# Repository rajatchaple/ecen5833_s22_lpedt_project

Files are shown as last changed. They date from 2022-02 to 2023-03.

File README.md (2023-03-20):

<h1 style="text-align: center;">CUBIT</h1>

## Background
Measuring tapes have been in use for centuries and are still the primary tool for taking measurements. However, they have several limitations, including the tedious process of taking and maintaining measurements and the fact that the measurements are single-use. Therefore, our team has designed a smart measuring instrument to digitize the data, which can be easily stored and accessed from anywhere.

## Summary
Our smart measuring instrument takes precise linear and angular measurements and transmits the data over to a mobile application using Bluetooth. The device have an encoder-wheel assembly that helps take measurements over a straight or curved surface accurately. A high precision rotary encoder provides high-resolution results, while an inertial measurement unit (IMU) sensor takes different angular and device orientation data. The device is powered by a small battery and contains an energy harvesting system using solar panels to recharge the battery. The device operates in low power mode by implementing load power management and utilizing minimum current for required peripherals.

<p align="center">
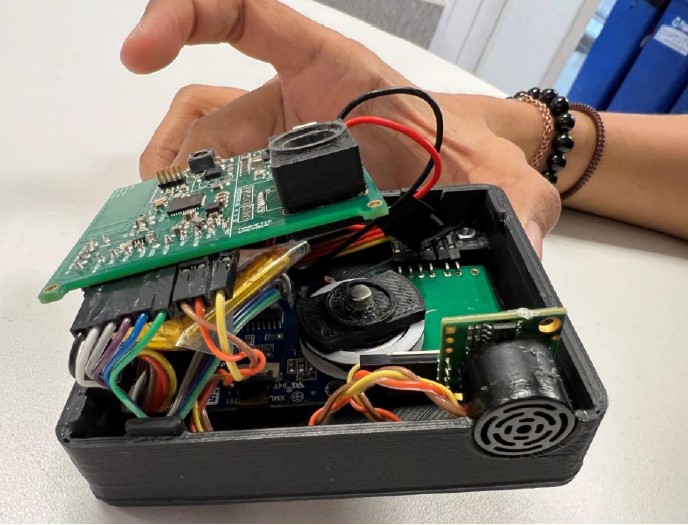
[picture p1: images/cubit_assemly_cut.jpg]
Cubit Assembly
  

## Getting Started

### Prerequisites:
* Altium Designer (for PCB design)
* Embedded C
* Bluetooth Low Energy (BLE) protocol basics
* Event-driven programming
* System design and implementation basics

### Installing:
* Install Altium Designer from [here](https://www.altium.com/downloads/altium-designer) (free for students). The project was designed using Altium Designer 22.10.1
* Install Simplicity Studio using this [link](https://www.silabs.com/developers/simplicity-studio). Set up the development environment for the EFR32BG13P732f512 microcontroller. This project works on sdk 3.2.3. It is easier to set up the environment with the [evaluation kit](https://www.silabs.com/documents/public/user-guides/ug279-brd4104a-user-guide.pdf). 

Following pages describe the approach used in development of this project over 15 weeks. This is a good example of how to design an embedded product from scratch.

## Hardware:

- [Selection of Components](https://github.com/rajatchaple/ecen5833_s22_lpedt_project/wiki/2.-Selection-of-Components)
- [Power management unit selection](https://github.com/rajatchaple/ecen5833_s22_lpedt_project/wiki/3.-Power-Management)
- [PMIC Simulation and Bulk capacitance](https://github.com/rajatchaple/ecen5833_s22_lpedt_project/wiki/4.-Bulk-Capacitance-Requirement)
- [Altium Schematic](https://github.com/rajatchaple/ecen5833_s22_lpedt_project/wiki/5.-Altium-Schematic)
- [Altium Layout Design](https://github.com/rajatchaple/ecen5833_s22_lpedt_project/wiki/6.-Altium-Layout-Design)
- [Fabrication and Assembly](https://github.com/rajatchaple/ecen5833_s22_lpedt_project/wiki/7.-Fabrication-and-Assembly)

## Software:
- LCD bring up
- IMU bring up
- Ultrasonic sensor bring up
- Encoder bring up
- Event driven programming
- BLE configuration
- Managing energy modes

## Application
Our product can be used to fulfill a majority of measurement requirements, including taking size data of a straight or uneven surface and taking angle measurements. It can be used in small industries, construction sites, fashion companies, and regular households. This product will eliminate the need to manually store measured data, and it will be low cost, low power-consuming with an energy harvesting mechanism. Additionally, it will use long-lasting rechargeable batteries, unlike single-usage dry cells.

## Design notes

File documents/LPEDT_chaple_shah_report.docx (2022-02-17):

ECEN 5833: Low Power Embedded Design Techniques

CUBIT

Smart Measuring Instrument

Team Name: Cubit

Team Members: Rajat Chaple

Saloni Shah

Table of Figures:

# Project Proposal

ECEN 5833: Low Power Embedded Design Techniques

CUBIT

Smart Measuring Instrument

Team Name: Cubit

Team Members: Rajat Chaple

Saloni Shah

## 1.1 Background

A measuring tape is used in a myriad of commercial businesses like construction, tailoring, warehouses as well as in day-to-day life. The first standard measuring tape was invented in 1850s and till now we have been using the same product. Although, since 18th century the world has advanced in every possible way, we still use the same measurement technique. The conventional measuring tape has ample of drawbacks like taking and maintaining measurements is very tedious, also all the measurements taken are majorly single use. It is high time that we modernize our method of taking measurements and digitize the data which can be easily stored and accessed from anywhere.

## 1.2 Project Summary

For the course project, our team is designing a smart measuring instrument which will have the capability to take precise linear and angular measurements and transmit the data over to a mobile application using Bluetooth. Primarily, this device will have an encoder-wheel assembly which can be used to take measurements over a straight or curved surface very accurately. A high precision rotary encoder will be helpful in giving high resolution results. Moreover, we will also install an inertial measurement unit (IMU) sensor to take different angular and device orientation data. Both measurements can then be transmitted to a mobile app connected to the product using Bluetooth. This data will also be displayed on an LCD. This device will run on a small battery, and it will also contain an energy harvesting system using solar panel to recharge the battery. All these components will be interfaced with a single Blue Gecko board. The device will operate in low power mode by implementing load power management and utilizing minimum current for required peripherals.

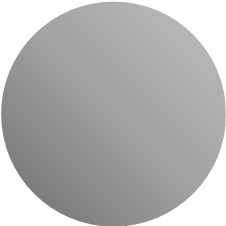
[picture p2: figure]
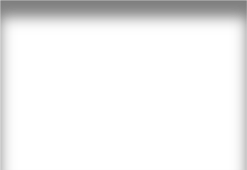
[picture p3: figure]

cm

108

0

°

Measuring Tape

Wheel fixed on

rotary encoder

LCD

Figure 1: Product Concept

## 1.3 Product Application

- This product can be used to fulfill majority of measurement requirements like taking size data of a straight or uneven surface and taking angle measurements.
- This product can be used in small industries, construction sites, fashion companies and regular households.
- This product will eliminate the need to manually store measured data.
- This product will be low cost, low power consuming with energy harvesting mechanism.
- This product will use long lasting rechargeable batteries unlike single usage dry cells.

## 1.4 Block Diagram

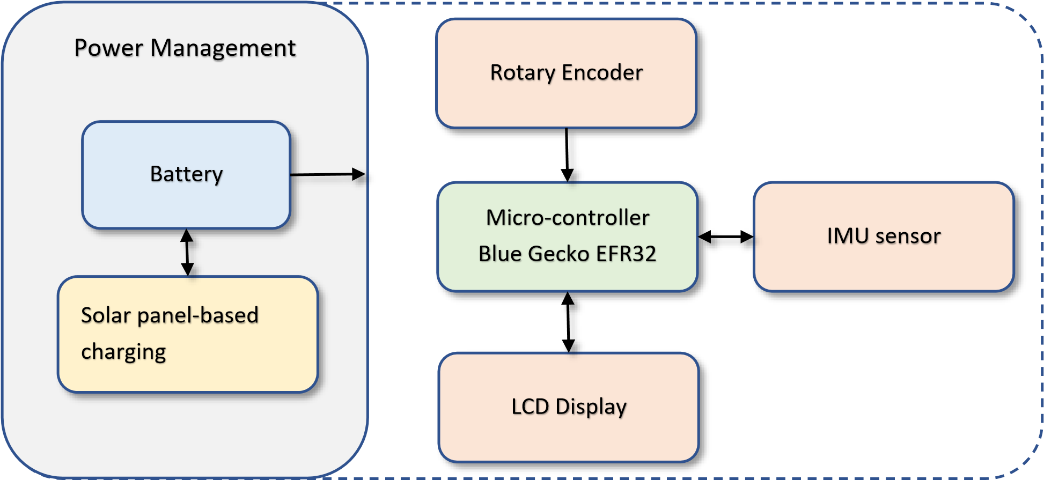
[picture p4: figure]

Figure 2: Block Diagram

## 1.5 Product Components

Table 1: Components List

Component | | Part No. | Load Power Management
Microcontroller | Silicon Labs Blue Gecko
Radio | EFR32BG13 | | ✓
Battery | Lithium Ion/Lithium Polymer | LP802036JU+PCM+2 WIRES (https://www.digikey.com/en/products/detail/jauch-quartz/LP802036JU-PCM-2-WIRES-50MM/9560981) 50MM Jauch Quartz | Batte (https://www.digikey.com/en/products/detail/jauch-quartz/LP802036JU-PCM-2-WIRES-50MM/9560981) Products | DigiKey (https://www.digikey.com/en/products/detail/jauch-quartz/LP802036JU-PCM-2-WIRES-50MM/9560981) (https://www.digikey.com/en/products/detail/jauch-quartz/LP802036JU-PCM-2-WIRES-50MM/9560981) | (https://www.digikey.com/en/products/detail/jauch-quartz/LP802036JU-PCM-2-WIRES-50MM/9560981)
PMIC | BQ25570 | BQ25570RGRT Texas (https://www.digikey.com/en/products/detail/texas-instruments/BQ25570RGRT/4430477) (https://www.digikey.com/en/products/detail/texas-instruments/BQ25570RGRT/4430477) Instruments | Integrated (https://www.digikey.com/en/products/detail/texas-instruments/BQ25570RGRT/4430477) (https://www.digikey.com/en/products/detail/texas-instruments/BQ25570RGRT/4430477) Circuits (ICs) | DigiKey (https://www.digikey.com/en/products/detail/texas-instruments/BQ25570RGRT/4430477) (https://www.digikey.com/en/products/detail/texas-instruments/BQ25570RGRT/4430477)
Buck Converter | TPS62842 Or PMIC internal buck converter | TPS62842DGRR Texas (https://www.digikey.com/en/products/detail/texas-instruments/TPS62842DGRR/12352343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) (https://www.digikey.com/en/products/detail/texas-instruments/TPS62842DGRR/12352343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) Instruments | Integrated (https://www.digikey.com/en/products/detail/texas-instruments/TPS62842DGRR/12352343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) (https://www.digikey.com/en/products/detail/texas-instruments/TPS62842DGRR/12352343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) Circuits (ICs) | DigiKey (https://www.digikey.com/en/products/detail/texas-ins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
Sensor | IMU sensor | BNO005 (To be acquired from Professor) | ✓
| Rotary Encoder | Magnetic Rotary (https://www.digikey.com/en/products/detail/ams/AS5147P-TS-EK-AB/5452349) (https://www.digikey.com/en/products/detail/ams/AS5147P-TS-EK-AB/5452349) Encoder (https://www.digikey.com/en/products/detail/ams/AS5147P-TS-EK-AB/5452349) (https://www.digikey.com/en/products/detail/ams/AS5147P-TS-EK-AB/5452349) Magnetic Wheel (https://www.digikey.com/en/products/detail/ams/RMH05-DK-XX-1-0/3712276) (https://www.digikey.com/en/products/detail/ams/RMH05-DK-XX-1-0/3712276) Assembly (https://www.digikey.com/en/products/detail/ams/RMH05-DK-XX-1-0/3712276) (https://www.digikey.com/en/product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 | ✓
| Ultrasonic Sensor | Adafruit Ultrasonic (https://www.digikey.com/en/products/detail/982/982-ND/5356850?itemSeq=389285645) (https://www.digikey.com/en/products/detail/982/982-ND/5356850?itemSeq=389285645)Sensor (https://www.digikey.com/en/products/detail/982/982-ND/5356850?itemSeq=389285645) (https://www.digikey.com/en/products/detail/982/982-ND/5356850?itemSeq=389285645) | ✓
HMI | LCD Display | Adafruit SHARP (https://www.adafruit.com/product/3502) (https://www.adafruit.com/product/3502) Memory Display (https://www.adafruit.com/product/3502) (https://www.adafruit.com/product/3502) Breakout - 1.3" (https://www.adafruit.com/product/3502) (https://www.adafruit.com/product/3502) (Acquired from Professor) | ✓
| Push Buttons | Available
Energy Harvesting System | Solar cells | Monocrystalline solar cells (https://www.digikey.com/en/products/detail/anysolar-ltd/KXOB25-12X1F-TB/9990434)

## 1.6 Proposed Product Demo

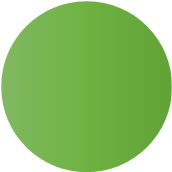
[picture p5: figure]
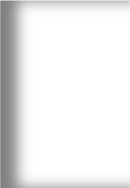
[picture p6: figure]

0

c

m

0

°

Measuring Tape

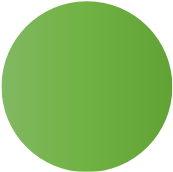
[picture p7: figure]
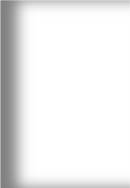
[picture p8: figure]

cm

36

0

°

Measuring Tape

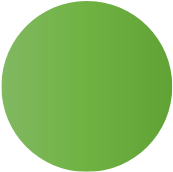
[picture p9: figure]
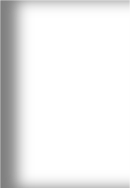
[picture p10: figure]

108

cm

0

°

Measuring Tape

Figure 3: Proposed Product Demo 1

As shown in the above image, this measuring tape can be used to measure any surface. The wheel encoder assembly installed on the product can be slid over a flat or uneven surface to get size value accurately. This measuring tape will have a high resolution in centimeter because of the use of a precision Rotary encoder with large number of pulse detection in a single rotation.

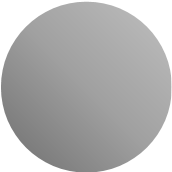
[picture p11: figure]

108

cm

0

°

Measuring Tape

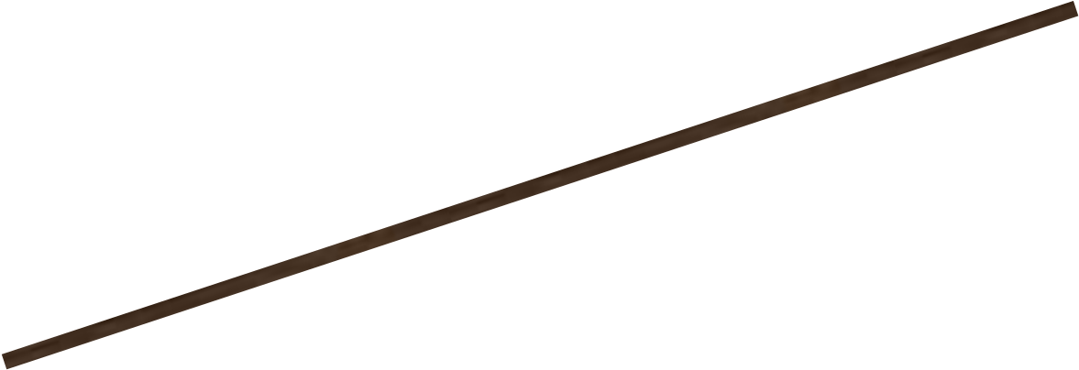
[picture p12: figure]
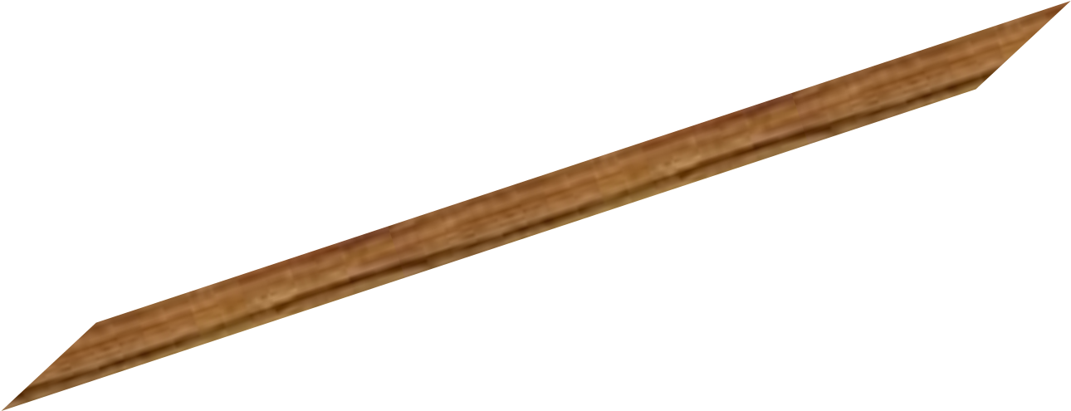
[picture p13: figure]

Figure 4: Proposed Product Demo 2

The above image shows how an angle measurement can be carried out using the product. This angle can be measured in any orientation of the device. The angle measurement will also be highly accurate due to the IMU sensor.

## 1.7 Product Features

- Free android app to store and manage measurement data
- Bluetooth connectivity of mobile phone with the device
- Rotary encoder-wheel assembly for linear measurement
- IMU sensor for accurate angle measurement
- LCD Display for better user experience
- Energy harvesting mechanism using solar panels
- Load power management by turning on only required peripherals
- Single rechargeable LiPo battery which can power the complete device

## 1.8 Product Specifications

- Dimensions: 100mm x 70mm
- Weight: 100g
- Wireless range: 100 m
- Size accuracy: ± 1 cm
- Angle accuracy: ± 1°
- Product Warranty: 2 years
- Operating Temperature: 0°C - 65°C
- Internal sensors and peripheral operating temperature:

Table 2: Temperature specifications for sensors

Sensor | Operating Temperature Constraints
Blue Gecko | -40 to 85 °C
IMU | -40 to 85 °C
Rotary encoder | -40 to 150 °C
LCD Display | -40 to 70 °C

# 1 Project Update 2

ECEN 5833: Low Power Embedded Design Techniques

CUBIT

Smart Measuring Instrument

Team Name: Cubit

Team Members: Rajat Chaple

Saloni Shah

Date: 01/29/2022

## 1.1 Activities accomplished in past week

- Studied mouse scroll-wheel encoder assemblies to decide the decide the mechanical assembly for final product. Disassembled 4 different optical mouses to explore different assemblies.

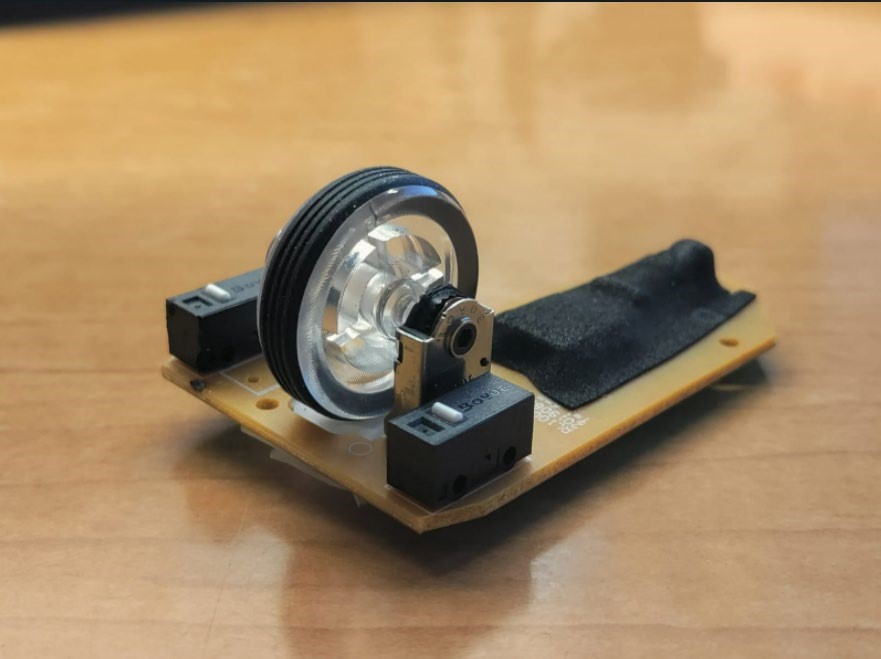
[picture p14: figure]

Figure 5: Scroll wheel encoder assembly

- Measured PPR(Pulse per rotation) of rotary encoder and circumference of wheel to estimate linear measurement resolution. o Finalized ultra-low power Graphic LCD display. o Estimated total power and energy consumption of the product.
- Worked on project planning and estimated timeline.

## 1.2 Activities for the coming week

- Finalize battery and solar panel based on energy consumption requirements. o Finalize Power management IC.
- Work on power supply circuit for the product.

## 1.3 Energy model for the product:

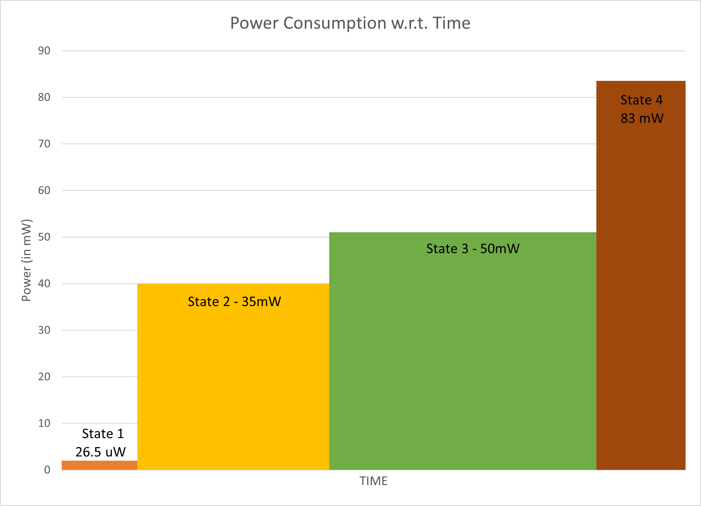
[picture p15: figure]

Figure 6: Energy model

## 1.4 Sensor selection:

### 1.4.1 IMU Sensor: BNO005

    - This sensor works on I2C as well as UART.
    - We will be interfacing the sensor using I2C as data transfer over UART communication takes longer and even though it consumes less energy, overall efficiency of UART decreases. Moreover, for transfer of larger data bytes I2C consumes the same amount of energy. (These assumptions were made using this reference (http://cc.oulu.fi/%7Ekmikhayl/site-assets/pdfs/2012_NTMS.pdf). (http://cc.oulu.fi/%7Ekmikhayl/site-assets/pdfs/2012_NTMS.pdf))
    - This sensor will require external load switch as after start-up it only enters low power mode and suspend mode. (Even in suspend mode it consumes 40uA of current).

### 1.4.2 Rotary encoder

    - This mechanical encoder has just 2 digital pins which can be wired directly as input to the controller. The encoder generated pulses gives the angular position of the axis and can then be converted to digital output.
    - The encoder will also require external load switch as it does not have internal circuitry to turn power off.

Online Project Management using Monday.com (https://view.monday.com/2210043877-dee7e4668b7b619c0c4a18486899a087?r=use1) (https://view.monday.com/2210043877-dee7e4668b7b619c0c4a18486899a087?r=use1)

## 1.5 Program Flowchart:

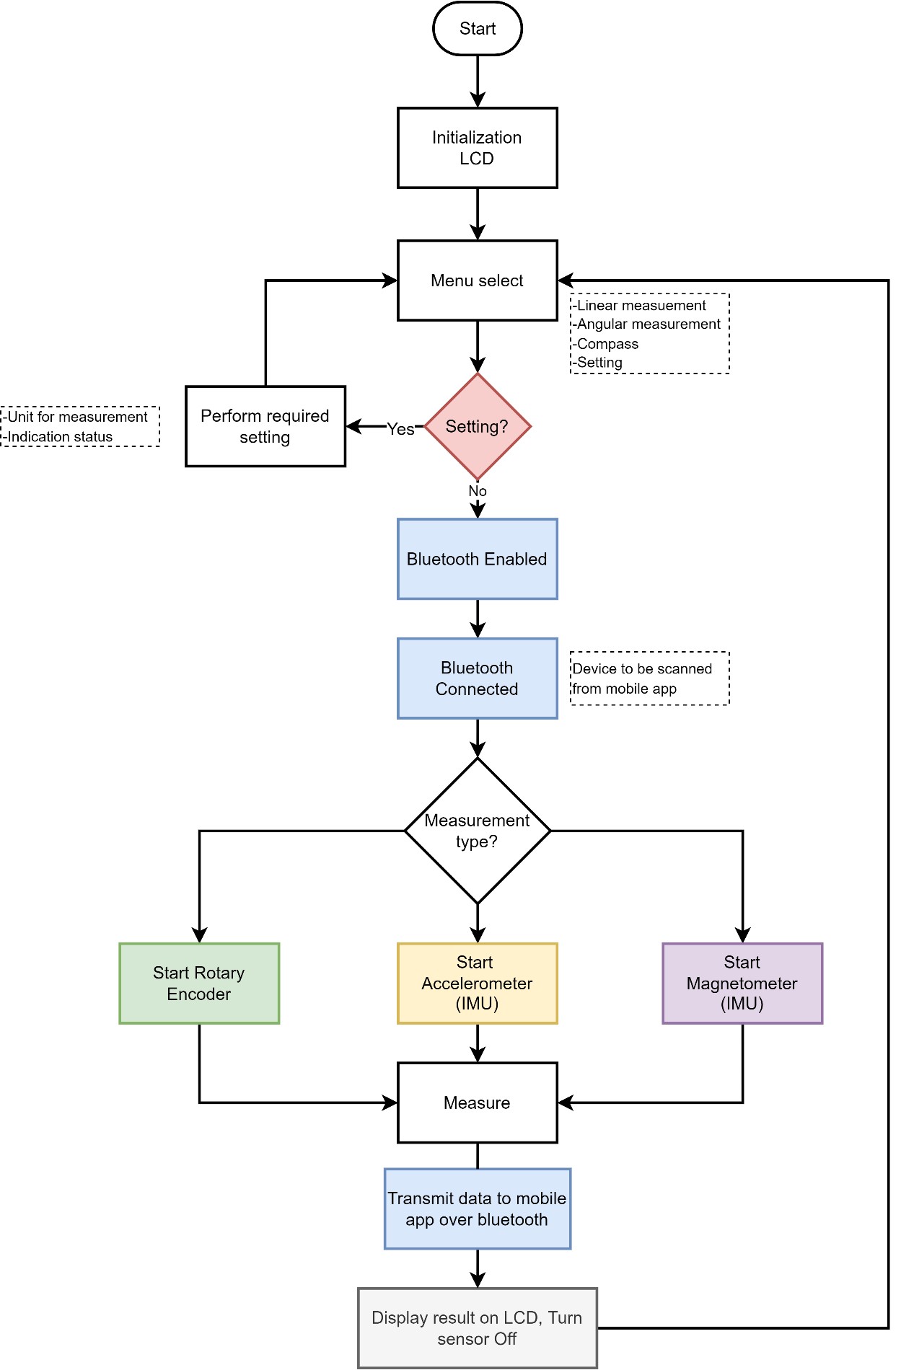
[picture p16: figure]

Figure 7: Flowchart

# 2 Project Update 3

ECEN 5833: Low Power Embedded Design Techniques

CUBIT

Smart Measuring Instrument

Team Name: Cubit

Team Members: Rajat Chaple

Saloni Shah

Date: 02/05/2022

## 2.1 Activities accomplished in past week:

- Finalized energy storage element (battery) based on energy consumption requirements.
- Finalized Power management IC and buck-converter IC.
- Practically implemented measurement system using mechanical rotary encoder, string-pulley assembly and interfaced it with Arduino. Found out that the rotary encoders have a limitation on how fast it can detect rotations i.e. it can only detect signals correctly at less than 160 rpm.

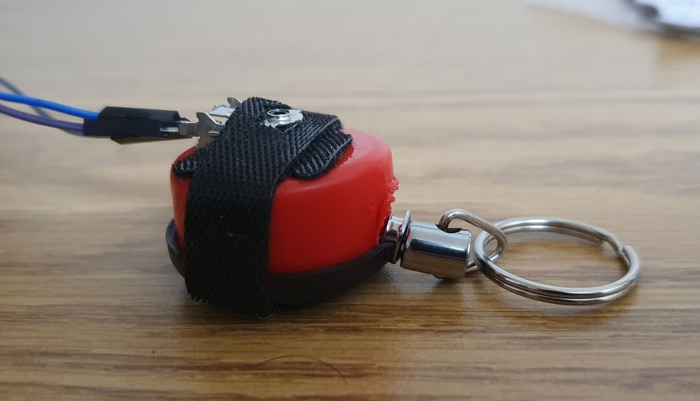
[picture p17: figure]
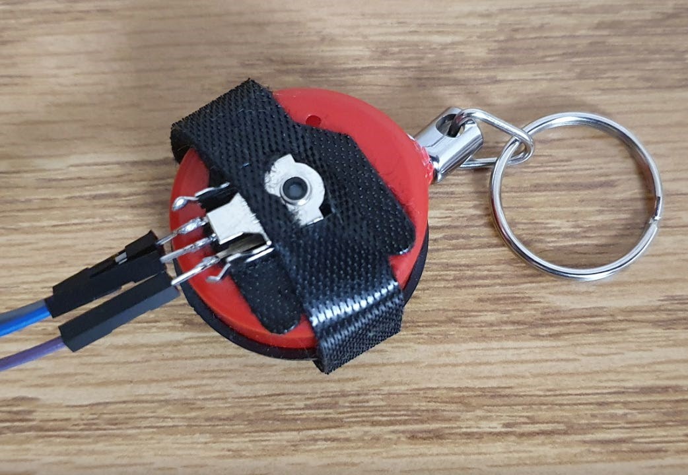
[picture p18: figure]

Figure 8: Assembled rotary encoder with a string-pulley

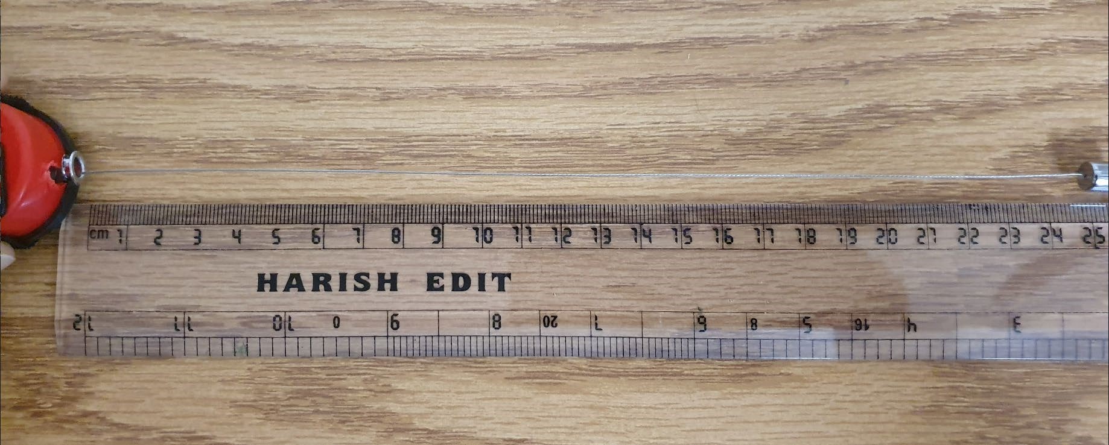
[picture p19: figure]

Figure 9: Measuring the length of a ruler using the assembly

Arduino serial monitor output with number of pulse counts and calculated length

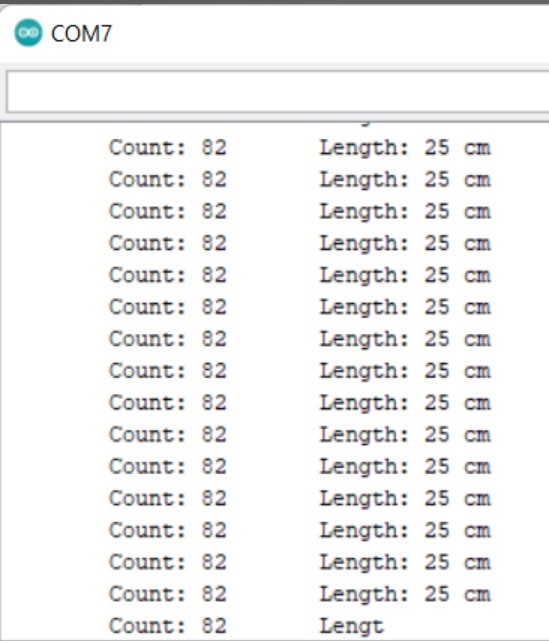
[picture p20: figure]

Figure 10: Optical Rotary Encoder output

- Changed the required rotary encoder from mechanical to magnetic due to speed constraints and higher chances of signal misses in the mechanical encoder.
- Finalized required magnetic rotary encoder and ultrasonic sensor for measurement applications.

## 2.2 Activities for the coming week

- Finalized energy harvesting element (solar panel) based on energy consumption requirements.
- Design product power supply circuit.
- Interface LCD display with Blue Gecko Evaluation Module.
- Finalize other required components for the product schematic design.

Power Storage Element Selection

o Expected runtime using supercapacitor = 1.36 hours

o Expected runtime using battery = 3 days (8 hours per day)¹

### 2.2.1 Super Cap vs Battery

Required peak current: 25 mA

Average current consumption: 13.68 mA

Average Charge requirement for continuous 8 hours operation: 110mAh

Average Energy Required for 8 hours of operation: 328.4 uWh

Ambient Temperature Conditions: Room Temperature (about 25° C)

Table 3: Super cap - Battery comparison

Super Cap | Battery
Steep discharge curve | Higher operating time
Large leakage current (30 uA) | Very less leakage current (2%/year)
Cannot handle required peak current | Can handle upto 1A peak current
Lower energy density | Higher energy density
Can operate in very low temperature | Dispenses less energy in low temperatures
Lower ESR power loss | Higher ESR power loss

Table 4: Supercap and battery specifications

Design Requirements | Super Cap (Tecate 100F) | Battery (Jauch 480mAh)
Useable Energy | 234.5J² - 18.6mAh | 480 mAh
Peak Discharge Current | | 1A
Recharge time | | 2 hours @ 0.5C
2 years of use, 300 charges | 500,000 cycles | 300 cycles ~ 80% capacity usage
Leakage current or rate | 3 uA | Less than 2-3%
ESR | 210 mΩ
Mechanical Dimensions | 12.5 x 25 mm | 38 x 20.5 mm

1 Refer attached spreadsheet for calculations
2 Refer attached spreadsheet

## 2.3 Power Management Unit Selection

### 2.3.1 Determining the required voltage range for the product

o To decide the operating voltage range for the product, we looked at the input voltage range of the peripherals utilized in the system. The below table shows the minimum and maximum input voltage range of the sensors and MCU.

Table 5: Voltage range for components[^1]

Sensor | Vin(min) | Vin(max) | Current Consumption
Blue Gecko | 1.8V | 3.8V | 4uA
IMU | 2.4V | 3.6V | 12.3mA
Rotary encoder | 3V | 3.6V | 15mA
LCD Display | 3V | 5V | 4uA

      - Based on the above calculations, we decided to operate all the peripherals at 3.0V as to utilize maximum possible battery capacity and increase the operating time of the system.
      - The approximate range of the supply voltage will be from 3.0-3.6V.

### 2.3.2 Determining the power management topology

- Considering that the power source battery gives maximum 3.7V and our required voltage supply for the peripherals is about 3.0V, which is always lower than supply voltage we decided to implement a buck converter to meet our power requirements.
    - The primary reason for choosing a buck converter as opposed to a buck-boost is that most Lithium-Poly batteries have a plateau from 3.5-3.6V

and very little charge below this plateau, limiting the usefulness of the buck-boost converter and its wide input voltage range[^2].

      - Moreover, the buck-boost converter also has one additional MOSFET as compared to the buck converter which increases power loss and decreases efficiency of the converter.
      - Keeping this in mind, we searched for a buck converter IC, with high efficiency, low quiescent current, low cost, and smaller footprint.
      - All these requirements were successfully met by the buck converter TPS62840[^3].

### 2.3.3 Determining Regulated or Unregulated Power Source

    - While deciding whether to use regulated or unregulated power source, we carried out following calculations to understand efficiency of both topologies.

Assumed product usage of 60 minutes or 3600 seconds

Assumed number of measurements in 1 hour, average of 20 measurements

Assumed period for one measurement, average of 13 seconds

On duty cycle = (20 measurements * 13 seconds) / 3600 = 7.2% Off duty cycle = 92.8%

TPS62840 Buck converter Efficiency Curve

    - Off duty cycle = 0.015-0.020 mA

Estimated 87.5% efficiency

    - On duty cycle = 15-20 mA range

Estimated 94% efficiency

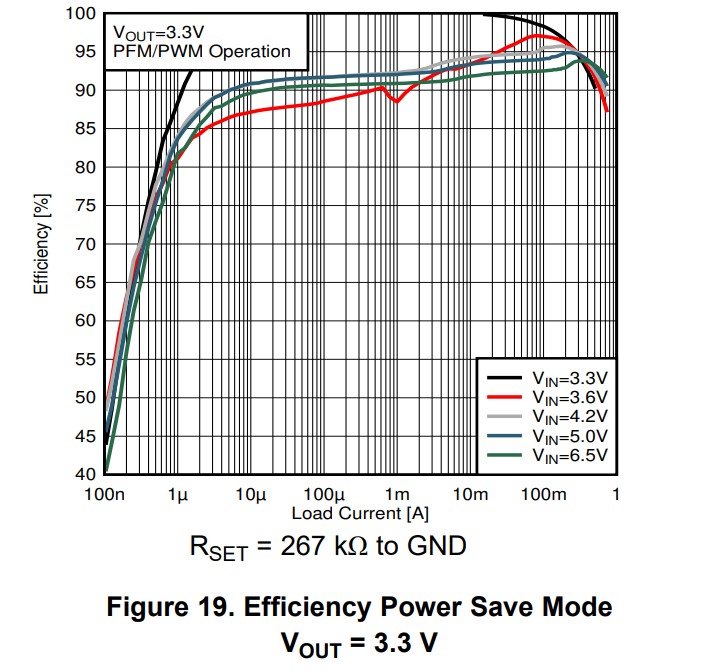
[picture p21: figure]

For regulated power case (using TPS62840 buck converter):

    - On duty cycle
    - TPS62840 efficiency ~3.6V input and 15,500uA is 94% + 0.06uA Iccq
    - Weighted avg power OOB = (On duty cycle * (15500 + 0.06) * 3.0V) / 94%
    - Weighted average power out of battery = 3561 uW o Off duty cycle
    - TPS62840 efficiency ~3.6V input and 20uA is 87.5% + 0.06uA Iccq
    - Weighted avg power OOB = (Off duty cycle * (20 + 0.06) * 3.0V) / 87.5%
    - Weighted average power out of battery = 63.8 uW o Total Average Power out
    - Weighted on duty cycle average power + Weighted off duty cycle average power = 3561uW + 63.8uW = 3624.825 uW

For unregulated power case (using Blue Gecko internal LDO):

- On duty cycle
    - Gecko efficiency ~3.6V input and 15,500uA is 83.33%
    - Weighted average power OOB = (On duty cycle * 15500 * 3.0V) / 83.33%
    - Weighted average power out of battery = 4017.7 uW o Off duty cycle
    - Gecko efficiency ~3.6V input and 20uA is 83.33%
    - Weighted average power OOB = (Off duty cycle * 20 * 3.0V) / 83.33%
    - Weighted average power out of battery = 66.81 uW o Total Average Power out
    - Weighted on duty cycle average power + Weighted off duty cycle average power = 4017.7uW + 66.81uW = 4084.5 uW

Increase in battery life using regulated power = 1 -

= 11.25%

Based on above calculations, we decided to use a regulated power source since it provides longer battery life. Moreover, we have a higher on duty cycle, higher power on to power off ratio, higher efficiency at light load and low quiescent current which justifies the use of regulated power source.

4.4. Determining the Power Management IC o The primary criteria for selecting a PMIC were low minimum input voltage limit to support very low voltage from energy harvesting element (solar cell) and efficient boost converter. A simple and efficient circuitry for energy harvester is required which were available in PMIC BQ25570.

- The input voltage supported in this IC is 0.1-5.1V. Also, many typical solar cells have an output voltage of 0.1V.
- Another important criterion is to have a wide range of input voltage from battery to support lower battery power which is 2-5.5V in case of BQ25570.
- This IC also has higher charging current capacity (maximum 285mA) for fast charging from external charger or a USB charging port.
- BQ25570 also has internal Programmable Maximum Power Point Tracking (MPPT) circuitry for optimal energy extraction from energy harvester like solar panel.
- Moreover, BQ25570 has internal boost as well as buck converter to boost low input voltage from the energy harvester and simultaneously regulate the output voltage[^4].

# 4 Project Update 4

ECEN 5833: Low Power Embedded Design Techniques

CUBIT

Smart Measuring Instrument

Team Name: Cubit

Team Members: Rajat Chaple

Saloni Shah

Date: 02/12/2022

## 4.1 Activities accomplished in past week:

- Generated Altium components library for following parts

Table 6: Components' library list

Sr. No | Part Description | Part Number | Footprint Name | Online SnapEDA/ Octopart Link
1 | Blue Gecko | EFR32BG13P732F512GM48-D | 48-QFN_7x7 | N/A
2 | PMIC | BQ25570RGRT | 21_QFN_35X35 | N/A
3 | IMU Sensor | BNO055 | LGA28R50P4X10_380X520X100 | BNO055 SnapEDA (https://www.snapeda.com/parts/BNO055/Bosch%20Sensortec/view-part/)
4 | Magnetic Encoder | AS5147P-HTSM | 14-TSOP_5x4_4 | N/A
5 | Resistor | RMCF0603FT1K00 | 2_Chip_0603_RMCF | N/A
6 | Capacitor | CL10A475KP8NNNC | CAP_0603_1MM | N/A
7 | Inductor | VLS3015CX-220M-1 | 2_IND_3x3 | N/A
8 | LED (red) | 150060RS75000 | LED_0603_RED_WL-SMCW | N/A
9 | LCD header | 3502 | LCD_SHARP_MEMORY_9_PIN | N/A

### 4.1.1 Change in the Power management strategy

  - With earlier update, plan was to use PMIC bq25570 and TPS62842 buck converter. Criterion for selection of external buck converter instead of one already integrated into bq25570 was Efficiency. However, considering ON duty cycle of the product operation, efficiency would no longer be a preliminary factor under consideration.
  - Also, major concern where we cannot utilize most energy from the battery was resolved using following.
    - Entire circuit would work at 3.15v
    - Buck converters have dropout voltage. This limits battery’s minimum usable voltage. As per datasheet, dropout voltage is maximum output current times the buck high side resistance.

Calculations:

Maximum output current: 35 mA

Maximum buck high side resistance: 200Ω

Dropout voltage: 35 x 200 = 0.7v

    - Usable battery would be in the range of 3.7v down to 3.22v.

### 4.1.2 Tested battery power consumption from a sample project

  - As a case study one of the sample projects was arranged. Though this project’s objective is entirely different than that of CUBIT, similarities in functional blocks were identified. This project also contains solar energy harvesting, PMIC and a load.

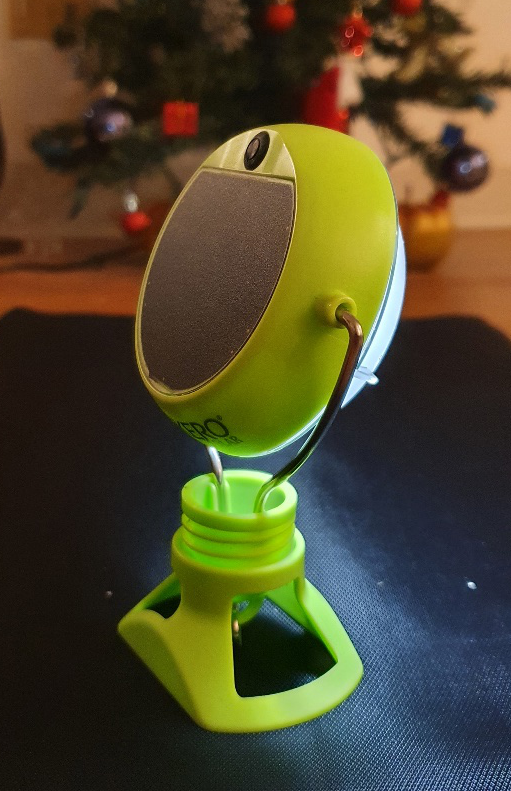
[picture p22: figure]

Energy Harvesting unit

Load
(Power LED)

Battery

(300 mAh)

Figure 11: Sample Product for case study

Calculations:

Continuous current consumption by Power LED = 55 mA

Theoretical battery backup=(Battery capacity(mAh))/(Continuous current consumption)

=500/55=9.09 Hrs

Objective: Solar power lamp

Battery capacity = 500mAh

No of Solar cells = 7 (part number unknown)

LEDs: 1 power LED of typical current consumption of 50mA

Solar Panel

Microcontroller

LED Driver

LED

Battery

Sample Project Block Diagram

Practically measured battery backup: 9 hours

If current consumption was 18mA, we would get battery backup of ~27 Hrs

Outcome of the experiment:

Our calculation for CUBIT falls between this range where battery backup for 480 mh battery with 18mA avg current consumption is around 24 Hrs. This verifies calculations against practical measurements.

  - Finalized solar cell unit

Calculations:

As per calculations in spreadsheet bq25570SolarAppDesign.xlsx,

Minimum solar panel area required is 8mW/cm²

As per datasheet: solar cell (https://waf-e.dubudisk.com/anysolar.dubuplus.com/techsupport@anysolar.biz/O18Adzn/DubuDisk/www/Gen2/KXOB25-12X1F%20DATA%20SHEET%20202007.pdf) (2994-KXOB25-12X1F-TB-ND), maximum peak power is 24.5mW per 1.54 cm²

This implies power/cm² =24.5mW/1.54cm^2

=15.90mW/cm^2

Selected component satisfies this requirement of minimum 8mW/cm²

### 4.1.3 Version tracking using GitHub

Updated previous updates, libraries and calculation documents to github

rajatchaple/ecen5833_s22_lpedt_project (github.com) (https://github.com/rajatchaple/ecen5833_s22_lpedt_project)

### 4.1.4 Timing information

Following are the critical timing parameters per module.

Table 7: Timing Information

Device | Parameter | Description | Min | Max
AS5147 (SPI) | tL | Time between CSn falling edge and CLK rising edge | 350 ns
| tH | Time between last falling edge of CLK and rising edge of CSn | 50 ns
| tMOSI | Data input valid to falling clock edge
BNO055 | fSCL | Clock frequency | | 400kHz
| fSUDAT | SDA Setup Time | 0.1 us
| HDDAT | SDA Hold TIme | 0 us
SHARP Memory LCD | fSCLK | Clock Frequency | | 1.1MHz
| tsSCS | SCS Setup time | 6 us
| thSCS | SCS hold time | 2 us
| tsSI | SI setup time | 250 ns
| thSI | SI hold time | 350 ns

### 4.1.5 Calculations for PMIC IC

- Studied reference design in bq25570 user guide (https://www.ti.com/lit/ug/sluuaa7a/sluuaa7a.pdf?ts=1644694996855) in order to understand PMIC circuitry for our application.
- Also, used calculator provided by TI on BQ25570 data sheet, product information and support | TI.com (https://www.ti.com/product/BQ25570) to calculate Resistor values.

### 4.1.6 Battery specifications

Table 8: Battery specifications

Parameter | Value
Battery nominal Voltage | 3.7V
Typical capacity | 500mAh
Minimum capacity | 480mAh
Charge voltage | 4.2V
Standard current | 0.2C-100 mA
Max charging current | 0.5C – 250mA
Cut-off voltage | 3V
Max discharging current | 2C-1A
Power rating | 1.78Wh

Battery Tolerances

Table 9: Battery Tolerances

Parameter | Value
Overcharge voltage | 4.28 V ± 0.025 V
Overdischarge voltage | 3.00 V ± 0.05 V
Over current range | 1.0A to 4.0A
Charging operating temperature | +10°C to +45°C
Discharging operating temperature | -20°C to +25°C

### 4.1.7 High risk elements:

- Magnetic interference of two sensors
  - IMU has a magnetometer which is to be used for compass and the rotary encoder is also based on magnetic pulse. These two components can interfere with each other and show incorrect reading. As a measure to mitigate this risk, we will be placing the two components physically as far as possible from each other on the board.
- EMI interference
  - Similar to the issue mentioned, the magnetic field from these components can also generate electromagnetic interference which can disrupt the functionality of other components on the board especially inverted F-antenna for Bluetooth connection (radio frequency can be disrupted due to electromagnetic interference). The potential solutions to overcome EMI are filtering, shielding, or grounding.
- Dual charging system (USB and Solar cell)
  - As a power storage component, we are using a rechargeable LiPo battery. To recharge this battery, we are planning on using energy harvesting component - solar cells. Apart from the solar cells, we also intend to have a 5V USB charging port on the board.
  - The major drawback in this design is the unavailability of a power management IC to efficiently switch between solar cells and USB port. Even if we interface a USB port, we have to have a circuit design such that reverse current does not flow from battery to our energy harvesting device and also to automatically switch between solar energy and USB input.
  - In this circuit design, we plan to use Schottky diodes for fast switching and low voltage drop. In case we are unable to successfully implement this design, we will be eliminating use of USB charging port and use the solar power as our primary recharge source.

### 4.1.8 Project Schedule:

Table 10: Project Schedule

Task | Deadline
Altium Components Libraries | Feb 12, 2022
Altium Product Schematic | Feb 26, 2022
Altium Product Layout | March 5, 2022
Product Final Layout for Fabrication | March 12, 2022
Send PCCB board for fabrication | March 19, 2022

We are aligned with our project timelines except the task where our plan was to bring up LCD module last week. We will be achieving this task in upcoming week. Instead, this week we focused on our case study of sample project to verify our energy calculations.

## 4.2 Activities planned for the upcoming week:

- Finalizing Bulk capacitance
- Implement LCD driver
- Schematic of Power Management Unit

[^1] IMU datasheet: BNO055 Datasheet (mouser.com) (https://www.mouser.com/datasheet/2/783/BST_BNO055_DS000-1509603.pdf) (https://www.mouser.com/datasheet/2/783/BST_BNO055_DS000-1509603.pdf) Blue Gecko datasheet: (https://www.silabs.com/documents/public/data-sheets/efr32bg13-datasheet.pdf)EFR32BG13 Data Sheet: Blue Gecko Bluetooth® Low Energy SoC Family (silabs.com) (https://www.silabs.com/documents/public/data-sheets/efr32bg13-datasheet.pdf) (https://www.silabs.com/documents/public/data-sheets/efr32bg13-datasheet.pdf) Magnetic Rotary Encoder datasheet: (https://www.digikey.com/en/products/detail/ams/AS5147P-TS-EK-AB/5452349)AS5147P-TS_EK_AB ams | Development Boards, Kits, Programmers | DigiKey (https://www.digikey.com/en/products/detail/ams/AS5147P-TS-EK-AB/5452349) (https://www.digikey.com/en/products/detail/ams/AS5147P-TS-EK-AB/5452349)LCD Display datasheet: (https://cdn-shop.adafruit.com/product-files/3502/Data+sheet.pdf)Data+sheet.pdf (adafruit.com) (https://cdn-shop.adafruit.com/product-files/3502/Data+sheet.pdf) (https://cdn-shop.adafruit.com/product-files/3502/Data+sheet.pdf)
[^2] EETimes - Buck-boost vs. buck converter: it's about battery life in portables (https://www.eetimes.com/buck-boost-vs-buck-converter-its-about-battery-life-in-portables/) (https://www.eetimes.com/buck-boost-vs-buck-converter-its-about-battery-life-in-portables/)
[^3] TPS62840 datasheet: (https://www.ti.com/lit/ds/symlink/tps62840.pdf?HQS=dis-dk-null-digikeymode-dsf-pf-null-wwe&ts=1644076764086)TPS62840 1.8-V to 6.5-V, 750-mA, 60-nA IQ Step-Down Converter datasheet (Rev. D) (https://www.ti.com/lit/ds/symlink/tps62840.pdf?HQS=dis-dk-null-digikeymode-dsf-pf-null-wwe&ts=1644076764086) (https://www.ti.com/lit/ds/symlink/tps62840.pdf?HQS=dis-dk-null-digikeymode-dsf-pf-null-wwe&ts=1644076764086) (ti.com) (https://www.ti.com/lit/ds/symlink/tps62840.pdf?HQS=dis-dk-null-digikeymode-dsf-pf-null-wwe&ts=1644076764086) (https://www.ti.com/lit/ds/symlink/tps62840.pdf?HQS=dis-dk-null-digikeymode-dsf-pf-null-wwe&ts=1644076764086)
[^4] BQ25570 internal buck converter vs external TPS62840 buck converter: The TPS62840 buck converter has higher efficiency at low current consumption than the internal buck converter.

Project Update #3

Project Update #4

Project Proposal

Project Update #2

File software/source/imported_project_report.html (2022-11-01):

# Project Import Summary

Import time | Apr 11, 2022, 3:45:45 PM
Original location | C:\Users\rajat\OneDrive\Low Power\Project\github\ecen5833_s22_lpedt_project\software\source\.cproject
Original project name | source
Original project type | Simplicity Studio (.sls)
Import mode | Copy contents

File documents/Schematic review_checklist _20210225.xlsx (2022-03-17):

 |  | Schematic Entry Review worksheet (Verstion 10-05-2019) | Schematic Entry Engineer Review comments /justifications | Partner 1 Engineer Schematic Review comments | Partner 2 Engineer (If team of 3) Schematic Review comments | SA Schematic Review 1 Comments | SA Schematic Review 2 Comments
 |  | Date: | 2022-02-27 | 2022-02-27
 |  | Engineeer/ Reviewer Name: | Saloni Shah | Rajat Chaple
 |  | Project name: Cubit
 |  | Circuits: Power Management, IO connection, Sensor interfacing, radio interface, HMI interface
1. Symbol Generation
 | a. Review all custom made .schLib files.
 |  | i. Verify that the schematic symbol is appropriate for the device function. | Schematic symbol designed using reference application design from datasheet | Schematic symbols verified
 |  | ii. If symbol is multipart, verify functional divisions make sense | Multipart symbols are EFR32 and BNO055. EFR32 has 3 parts - radio and antenna interface, IO port, power decoupling and supply. BNO055 has 2 parts - application pin connections and noconnect pins | Multipart symbols verified
 |  | iii. Make sure all component pins are accounted for on symbol(s). (Count them!) | Verified | Verified
 |  | iv. Verify the schematic pin #s match the data sheet. | Verified | Verified
 |  | v. If thermal pad is required, verify that a pin is specified for the pad and connected to ground. | Thermal pad is required in EFR32, BQ25570 only. Pads connected to ground. Verified | Thermal pads verified. Pads adjusted in footprint as well to get appropriate solder mask
 |  | vi. Review that the same IC package is selected on the merchant website and on the parameter entry in schematic symbol. | Verified | Verified
 | b. Verify that all the Parts have their part numbers updated. |  | Verified | Verified
 | c. Verify that all the segments of a multipart component have the same reference designator assigned. |  | Verified | Verified
2. Component Selection
 | a. Decoupling capacitor selected should be rated for 175 to 200% of the voltage on the rail. |  | 220uF and 100uF used in PMIC bulk capacitance and decoupling capacitance is rated at 6.3V, this was the highest available value. Rest of the capacitors are rated at higher voltages | Verified
 | b. Guideline, not rule: All resistor 0603 or justify a different size |  | All resistors used are 0603 | Verified
 |  | i. space constraints demand smaller, (don’t go smaller than 0402)
 |  | ii. or use case power requires larger
 | c. Guideline, not rule: All Caps 0805 or justify a different size |  | Most capacitors used are 0805 | Verified
 |  | i. space constraints demand smaller, (don’t go smaller than 0402)
 |  | ii. or capacitance requires larger package, | 220uF capacitor is larger (1210) as smaller size is not available | Capacitance calue verified using SimSurfer taking into account DC bias
 |  | iii. or smaller part required to achieve desired response frequency. | Smaller capacitance on antenna connection require 0402 part | Verified
3. Page Layout
 | a. Block diagram on first page. |  | Done by Rajat | Completed
 | b. Functional blocks grouped logically on pages |  | Verified | Verified
 | c. Pages not overcrowded |  | Verified | Verified
 | d. Schematics designed to print on 8.5 x 11” page (OK to use 'B' size sheet and shrink to print.) |  | Verified | Verified
 | e. Title blocks on all pages? Properly filled in? |  | Verified | Verified
4. Design
 | a. For every IC
 |  | i. Check voltages on each part. Verify that signals connecting devices are at the same voltages or are open collector (open Drain) signals. | All components can be configured between 3-3.6V. We are operating them at 3.2V for maximum battery usage | VOUT of 3.2V gives satisfies minimum requirement of all circuit components
 |  | ii. Check whether each signal pin is open drain, and if yes, is there a pull-up resistor. | N/A | N/A
 |  | iii. Verify the no device on a given bus will be powered down and pull the bus signals low when other devices are trying to communicate. | Verified | Verified
 | b. Go through the PMU datasheet to understand the settings.
 |  | i. Verify that the maximum voltages on any pins are within the device’s PMU specifications. | Verified | Verified
 |  | ii. Go through each PMU pin specification in order of the data sheet | Verified | Verified
 |  | iii. Check whether each pin requires a decoupling capacitor. | Verified (followed typical application for guidance) | Verified
 |  | iv. Show math for calculating all feedback components - best to show math on schematic. | Calculated using the excel sheet resource provided by TI | Verified the excel sheet calculation with equations given in PMIC datasheet
 |  | v. Show math for calculating all compensation components - best to show math on schematic. | Calculated using the excel sheet resource provided by TI | Verified the excel sheet calculation with equations gven in PMIC datasheet
 | c. What is the planned cut-off voltage of the battery? |  | 2 V
 |  | i. Confirm that the PMU is set to disable power to the digital circuit when the battery goes below the cut-off voltage | Internally managed by the PMIC | Verified
 | d. If design is different from reference schematic from vendor, why? |  | Same design except addition of Bulk capacitance on VSTOR and schottkey diode assembly on LBOOST input to handle input from USB connector | Design change verified by detailed study of PMIC datasheet
 |  | i. Justify changes
 | e. If super capacitor is chosen as the storage device, check for the leakage current. |  | N/A | N/A
 | f. Verify if the different modules can be isolated from each other to ease the testing process. |  | Load switches are connected before each sensor and LCD module for isolation. Jumper connection is added between PMIC and microcontroller for isolation | Load switches connected between power from microcontroller correctly. Can have additional jumpers before load switches for testing during development
 | g. Add a header on the energy harvester to check for current consumption. |  | Test point added on the solar panel output | Verified
 | h. If using UART and if the microprocessor is an EFM32LG, an external oscillator will be required as the RC Oscillator isn’t accurate enough to run at 9600 baud rate. |  | N/A | N/A
 | i. Every power pin on a part or header should have a decoupling capacitor. |  | Verified | Verified
 | j. Does design have an appropriate programming connector or method? |  | Debug connector added to EFR32 | Debug connector interfacing verified from AN958
 |  | i. Does design provide enough power for programming MCU or does it have an alternate programming power connection? | No alternate programming power connection required | Verified
 | k. Can battery or cap be initially powered in reasonable time?
 | l. Does schematic have extra GND test point pins to be spread around board? (6-8?) |  | Not required. All test points have adjacent ground connection | Verified
 | m. Test point pins on busses? |  | Verified | Verified
 | n. Test point pins on interrupts? |  | Verified | Verified
 | o. Extra test pins on spare IO for scope triggers for profiling? |  | Verified | Verified
 | p. Consider adding LED indicators, especially on the power rails and add it close the subsystem under test (easy to identify if the subsystem is powered on/off). |  | Added indicator LEDs on multiple parts of the board | Verified
5. Wiring
 | a. Verify the direction and use of the LEDs. |  | Verified | Verified
 | b. Verify that the GNDs have all the same name where ever required. |  | Verified | Verified
 | c. Verify that all appropriate power lines have the same name. |  | Verified | Verified
 | d. Verify any communication lines:
 |  | i. If one part will be active while another one is powered off on the line, is there a condition where an ESD diode could be pulling the line down? | No such connection made | Verified
 | e. Verify whether any UART RTS and CTS lines need to be shorted or left open. |  | Not required. | Verified
 | f. Verify that the micro controller UART TX pin connects to the RX pin of the slave device and that the TX pin of slave device connects to the RX pin of the microcontroller. |  | Verified. Ultrasonic sensor output TX pin is connected to EFR32 RX pin | Verified
 | g. Verify that the RESET pin is connected correctly as per the functionality (Active Low/Active High). |  | Verified. Using reference from EFR32 mainboard schematic | Verified
 | h. Reset button with proper pull-up / capacitor configuration |  | Verified | Verified
 | i. Can you justify the reset metodology for each digital component? |  | Reset not required for the other modules or sensors. | Verified
 | j. All signals should be correctly named. Do not use Altium default signal names. |  | Verified | Verified
 | k. Corectly name the signals of the communication lines in the schematics for ease in debugging. |  | Verified | Verified

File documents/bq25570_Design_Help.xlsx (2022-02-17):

User Input | VBIAS | 1.21 | V
Fixed
 | Comparator threshold for VSTOR of charger. |  |  |  |  | Comparator threshold voltages indicating when |  |  |  |  | For the bq25570 only, comparator threshold |  |  |  |  | Maximum power point threshold, e.g. ~0.7-0.8 of
 | Typically the max storage element voltage, |  |  |  |  | VSTOR has risen above VBAT_OK_HYST or fallen |  |  |  |  | for VOUT of buck converter. |  |  |  |  | solar panel's open circuit voltage.
 | e.g. 4.2V for LiIon battery. |  |  |  |  | below VBAT_OK.
 | VBAT_UV < VBAT_OV < 5.5V |  |  |  |  | VBAT_OV > VBAT_OK_HYST > VBAT_UV |  |  |  |  | 1.3V < VOUT < VBAT_OV |  |  |  |  | MPPT
Desired |  |  |  |  |  | RSUM1 | 13 | MW |  |  |  |  |  |  |  | RSUM1 | 20 | MW
Desired | RSUM1 | 13 | MW |  |  | VBAT_OK | 2.8 | V | > VBAT_UV |  | RSUM1 | 13 | MW |  |  | VIN_DC(OC) | 1 | V | Open Circuit Volts
Desired | VBAT_OV | 4.2 | V |  |  | VBAT_OK_HYST | 3.1 | V | > VBAT_OK |  | VOUT | 1.3 | V |  |  | VREF_SAMP | 0.9 | V | MPP voltage
 |  |  |  |  |  |  |  | closest 1% resistor1 |  |  |  |  |  |  |  |  |  | closest 1% resistor1
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

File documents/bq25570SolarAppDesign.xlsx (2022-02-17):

User Input
Computed/Fixed
 |  |  | VSTOR nominal | 3.00 | V |  |  |  |  | VBAT_UV < VSTOR nominal <= VBAT_OV
System Loads | VOUT (V) | IOUT (mA) | Est Buck Effcy per datasheet | ISTOR = (VOUTxIOUT) / (VSTORnom x Effcy) (mA) | Mode Duration (how long?) (s) | Mode Period (how often?) (s) | Mode Hours / Day = 24 hours x duration/ period | mAHr / Day = ISTOR X Mode Hrs / Day | mWHr / Day = VSTOR x mAHr / Day
Active Mode 1 - bq25570 VOUT | 1.800 | 49.500 | 0.930 | 31.935
Active Mode 1 - bq25570 VSTOR |  |  |  | 8.000 |  |  |  |  |  | Direct loading on VSTOR
Totals for Active Mode 1 |  |  |  | 39.935 | 0.040 | 60.000 | 0.016 | 0.639 | 1.917
Active Mode 2 - bq25570 VOUT | 1.800 | 6.500 | 0.850 | 4.588 |  |  |  |  |  | If only one active mode, enter 0 for IOUT.
Active Mode 2 - bq25570 VSTOR |  |  |  | 5.500 |  |  |  |  |  | If only one active mode, enter 0 for ISTOR.
Totals for Active Mode 2 |  |  |  | 10.088 | 0.125 | 60.000 | 0.050 | 0.504 | 1.513
Sleep Mode - bq25570 VSTOR (1.8V rail off) |  |  |  | 0.100 |  |  | 23.934 | 2.393 | 7.180 | Idle mode hours / day = 24 minus active mode hours / day
bq25570 quiescent current + storage element leakage current |  |  |  | 0.001 |  |  | 24.000 | 0.024 | 0.072 | Storage element leaks all the time.
 | Total mAHr / day consumed |  |  |  |  |  |  | 3.561 | mAHr / day
 | Multiply by max consec dark days (e.g. not charging when overcast or raining) |  |  |  |  |  |  | 2.000 | days / week
 | Recommended minimum battery capacity |  |  |  |  |  |  | 7.122 | mAHr
 | -OR-
 | Mininum super capacitor voltage |  |  |  |  |  |  | 2.500 | V | VBAT_UV = 2.0V > Min super capacitor > VSTOR nominal
 | Maximum super capacitor voltage |  |  |  |  |  |  | 4.000 | V | VSTOR nominal < Max super capacitor voltage <= VBAT_OV
 | Recommended minimum super capacitance |  |  |  |  |  |  | 15.777 | F | Min Bat Capacity / 1000 x 3600s/hr x VSTORNOM = 1/2 x CSUPER x (Vmax2 - Vmin2)
 |  | Total mWHr / day consumed |  |  |  |  |  |  | 10.682 | mWHr / day
 |  | Multiply by operating days per week |  |  |  |  |  |  | 7.000 | days / week
 |  | Total mWHr /week required for system operation for the week |  |  |  |  |  |  | 74.776 | mWHr / week
 |  | Divide by charging days per week |  |  |  |  |  |  | 5.000 | days / week | Operating days minus max consecutive dark days
 |  | Total mWHr / day required to be collected by solar panel during charging days |  |  |  |  |  |  | 14.955 | mWHr / day | Total 7-day power must be collected during 5 charging days
 |  | Divide by charging hours / day |  |  |  |  |  |  | 8.000 | hours / day | i.e., includes excess energy for charging the battery
 |  | Instantaneous power required from the solar panel |  |  |  |  |  |  | 1.869 | mW
 |  |  | Divide by low estimate of bq25570 efficiency per datasheet |  |  |  |  |  | 0.800
 |  |  | Minimum input power required for system operation |  |  |  |  |  | 2.337 | mW
 |  |  |  | Divide by panel power per panel datasheet |  |  |  |  | 8.000 | mW/cm2 | Use power from lowest expected light level
 |  |  |  | Minimum solar panel area required |  |  |  |  | 0.292 | cm2

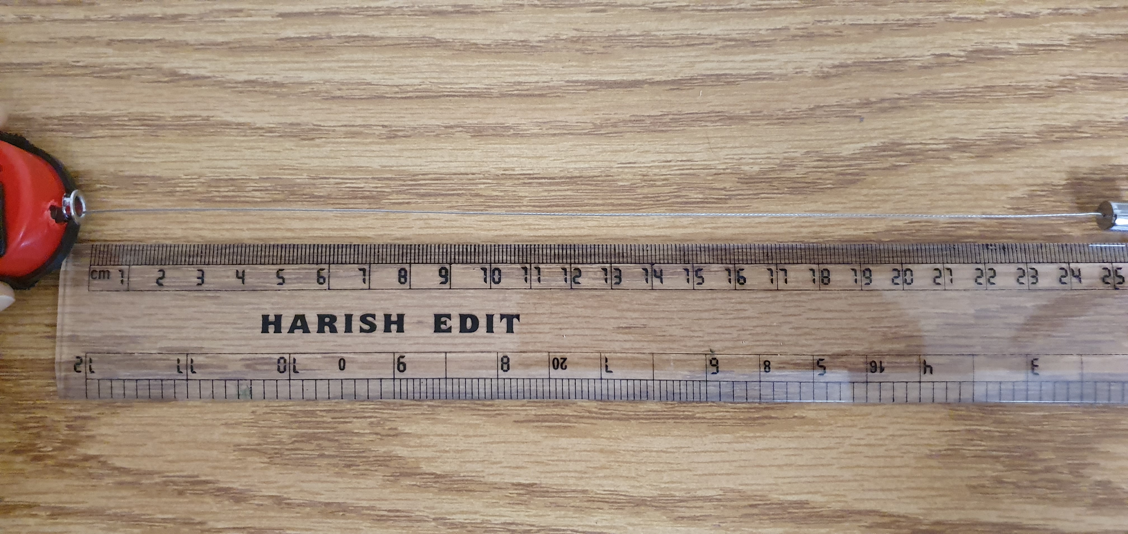
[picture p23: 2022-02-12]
images/Optical Rotary encoder 2.jpg

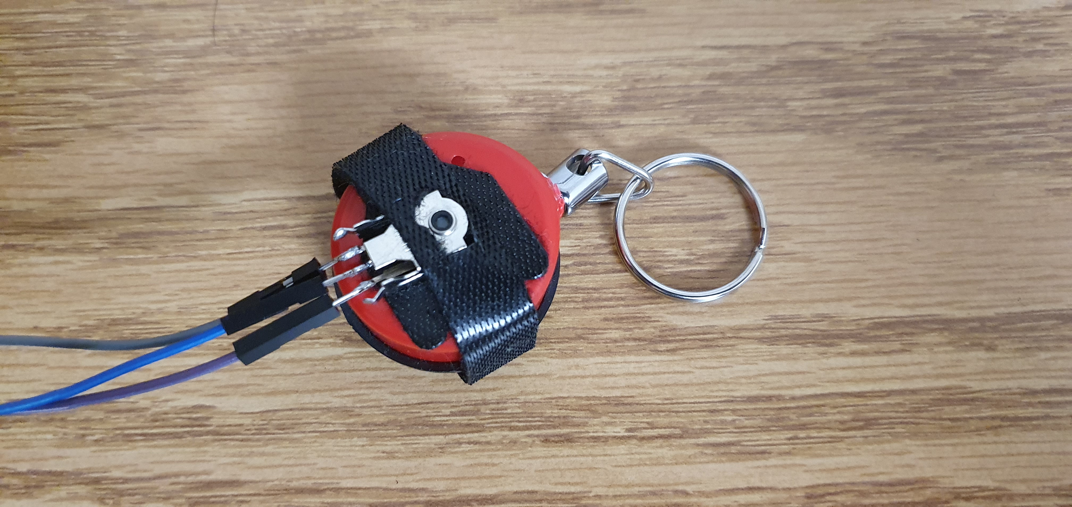
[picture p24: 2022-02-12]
images/Optical Rotary encoder 3.jpg

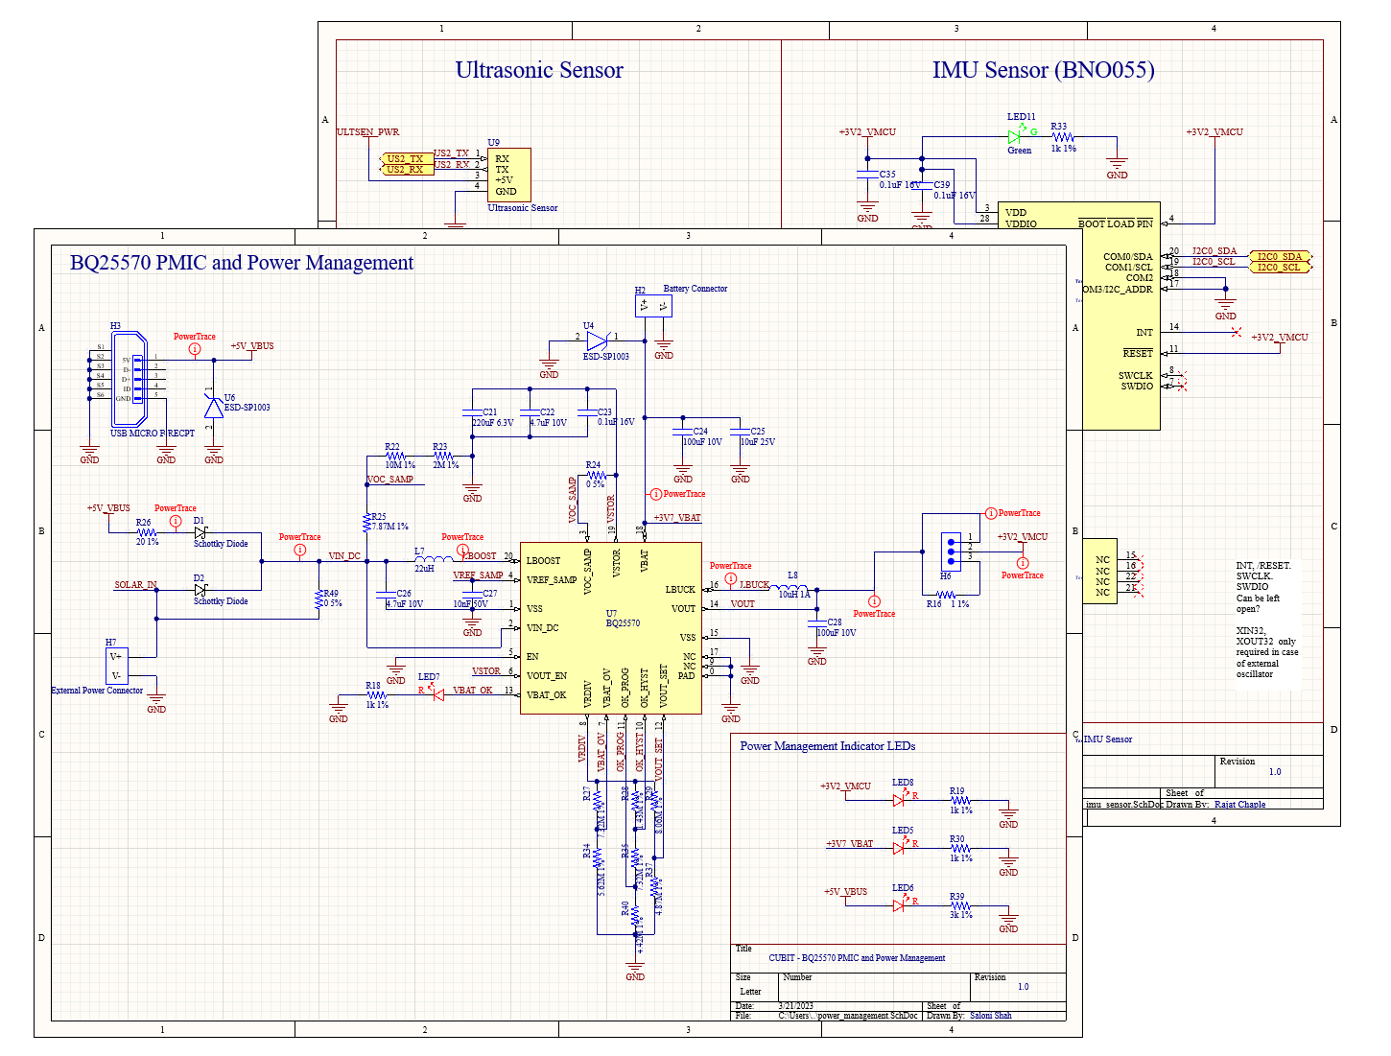
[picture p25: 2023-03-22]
images/schematics_collage.png

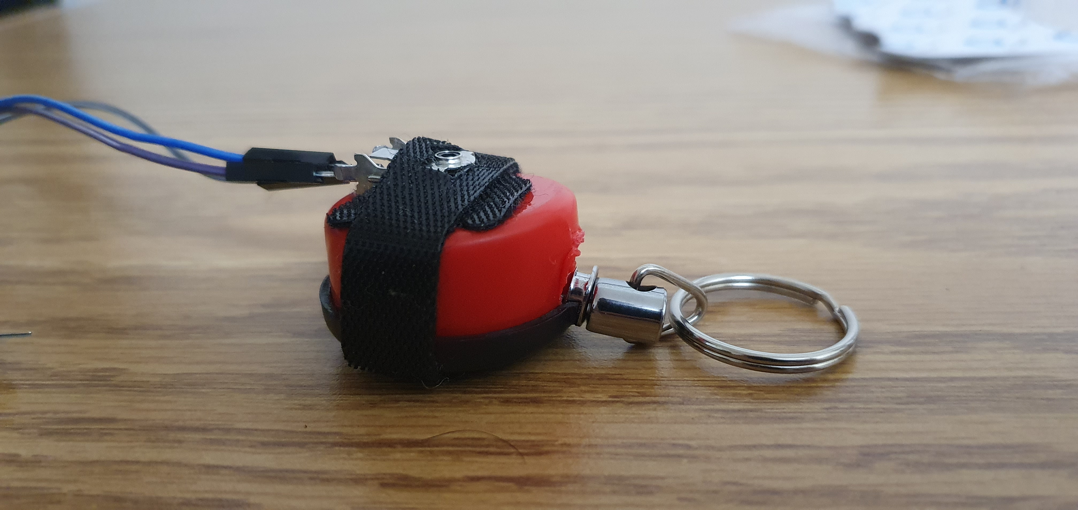
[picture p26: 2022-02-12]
images/Optical Rotary encoder 1.jpg

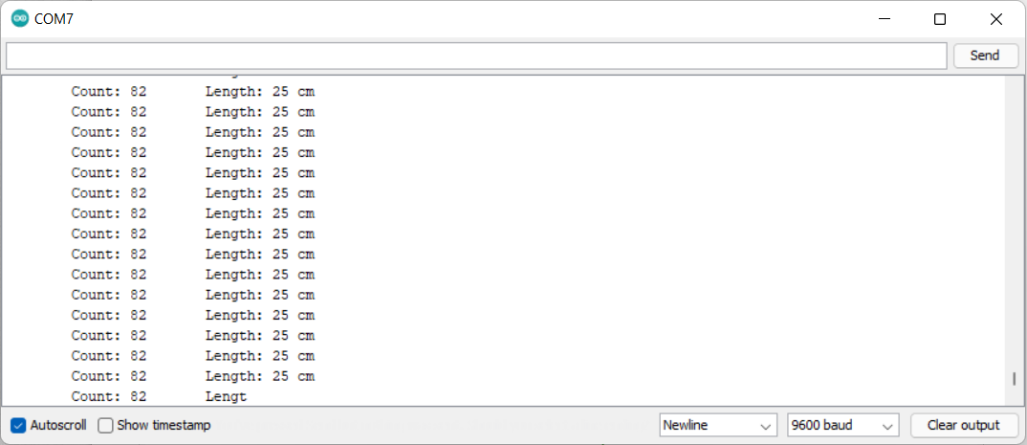
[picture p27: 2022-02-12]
images/Optical Rotary Encoder output.png

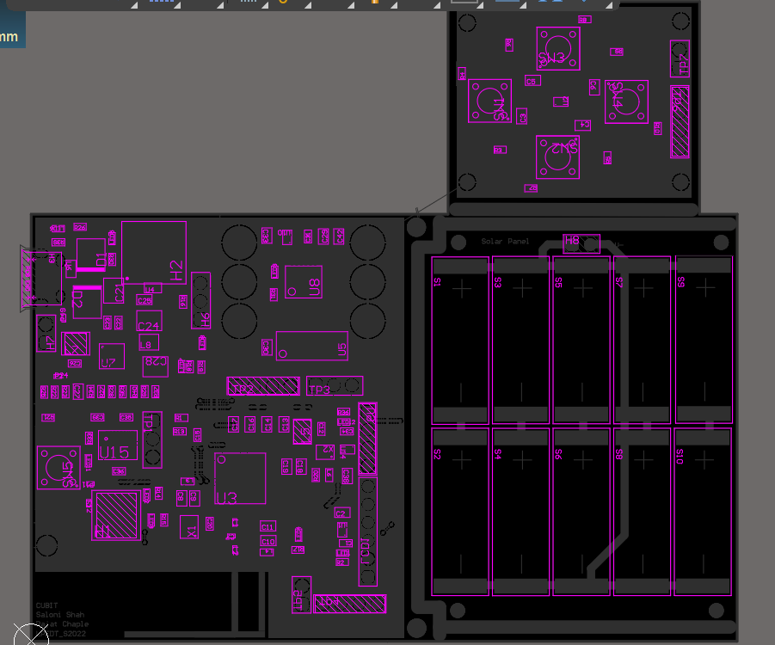
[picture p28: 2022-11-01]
hardware/lpedt_project_board_cubit/Screenshot 2022-04-06 115455.png

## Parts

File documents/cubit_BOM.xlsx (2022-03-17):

Parts ordered from Digi-Key
Comment | Description | Designator | Footprint | LibRef | BOM Quantity | Order Quantity | Unit Price | Order Amount | Case/Package | Manufacturer | Manufacturer Part Number | Supplier 1
F_ANT |  | A1 | F_ANTENNA_FOOTPRINT | F_ANT | 1
0.1uF 16V | Cap Ceramic 0.1uF 16V X7R 10% SMD 0805 125°C Paper T/R | C1, C15, C20, C23, C31, C32, C35, C36, C37, C39 | CAP_0805_02X125 | C0805C104K4RACAUTO | 10 | 20 | 0.162 | 3.24 | 0805 | KEMET | C0805C104K4RACAUTO | Digi-Key
10uF 25V | Cap 0805 25 V 10 uF ±20% Tolerance X5R Monolithic Ceramic Chip Capacitor | C2, C13, C18, C25, C29, C30, C33, C34, C38, C40, C41, C42, C44, C46 | CAP_0805_02X125 | GRM21BR61E106KA73K | 14 | 50 | 0.094 | 4.7 | 0805 | Murata | GRM21BR61E106KA73K | Digi-Key
1nF 50V | 1nF ±10% 50V X7R 0805 | C3, C4, C5, C6 | CAP_0805_02X125 | CL21B102KBANFNC | 4 | 10 | 0.043 | 0.43 | 0805 | Samsung | CL21B102KBANFNC | Digi-Key
1.5pF 50V | Cap Ceramic 1.5pF 50V C0G 5% Pad SMD 0402 125C Automotive T/R | C7 | CAP_0402_1mm | GCM1555C1H1R5JA16D | 1 | 10 | 0.047 | 0.47 | 0402 | Murata | GCM1555C1H1R5JA16D | Digi-Key
100pF 50V | Cap 0.1nF ±10% 50V X7R 0805 | C8 | CAP_0805_02X125 | CC0805KRX7R9BB101 | 1 | 3 | 0.11 | 0.33 | 0805 | Yageo | CC0805KRX7R9BB101 | Digi-Key
10pF 50V | Cap Ceramic 10pF 50V X7R 10% SMD 0805 125°C Paper T/R | C9, C11 | CAP_0805_02X125 | C0805C100K5RACTU | 2 | 5 | 0.29 | 1.45 | 0805 | KEMET | C0805C100K5RACTU | Digi-Key
220nF 50V | Cap 220nF ±10% 50V X7R 0805 | C10 | CAP_0805_02X125 | CC0805KKX7R9BB224 | 1 | 3 | 0.18 | 0.54 | 0805 | Yageo | CC0805KKX7R9BB224 | Digi-Key
4.7uF 10V | Cap CL10 Series 4.7 uF 10 V ±10 % Tolerance X5R SMT Multilayer Ceramic Capacitor | C12, C22, C26 | CAP_0603_1MM | CL10A475KP8NNNC | 3 | 10 | 0.047 | 0.47 | 0603 | Samsung | CL10A475KP8NNNC | Digi-Key
1uF 25V | Cap 1 µF ±10% 25V Ceramic Capacitor X5R 0805 (2012 Metric) | C14, C16, C17 | CAP_0805_02X125 | GRM216R61E105KA12D | 3 | 10 | 0.266 | 2.66 | 0805 | Murata | GRM216R61E105KA12D | Digi-Key
10nF 50V | Cap 10nF ±10% 50V X7R 0805 | C19, C27 | CAP_0805_02X125 | CL21B103KBCNNNC | 2 | 10 | 0.05 | 0.5 | 0805 | Samsung | CL21B103KBCNNNC | Digi-Key
220uF 6.3V | Cap 220uF 6.3volts X5R 20% | C21 | Chip_1210_3.2x2.5 | GRM32ER60J227ME05L | 1 | 2 | 1.62 | 3.24 |  | Murata | GRM32ER60J227ME05L | Digi-Key
100uF 10V | Cap 100uF ±20% 10V X5R 1210 | C24, C28 | Chip_1210_3.2x2.5 | CL32A107MPVNNNE | 2 | 4 | 1.14 | 4.56 | 1210 | Samsung | CL32A107MPVNNNE | Digi-Key
Schottky Diode | LSM115J Series 15 V 1 A Surface Mount Schottky Rectifier - DO-214BA | D1, D2 | SCHOTTKY4336X33N | LSM115JE3/TR13 | 2 | 4 | 0.56 | 2.24 |  | Microchip | LSM115JE3/TR13 | Digi-Key
Debug Port Header | CONN HEADER SMD 10POS 1.27MM. Connector Header Surface Mount 10 position 0.050" | H1 | Amphenol_20021121_0 | 20021121-00010C1LF | 1 | 2 | 0.93 | 1.86 |  | Amphenol ICC / FCI | 20021121-00010C1LF | Digi-Key
Battery Connector | 2.00mm Pitch Mi ll System Wire-to-Board Header, Surface Mount, Single Row, Vertical, 2 Circuits | H2 | BAT_CONN | ‎PRT-09914 | 1 | 2 | 0.95 | 1.9 |  | SparkFun | ‎PRT-09914 | Digi-Key
USB MICRO B RECPT | USB - micro B USB 2.0 Receptacle Connector 5 Position Surface Mount, Right Angle; Through Hole | H3 | MICROUSB_AMPHENOL_10118194-0001LF | 10118194-0001LF | 1 | 2 | 0.48 | 0.96 |  | Amphenol FCI | 10118194-0001LF | Digi-Key
External Power Connector |  | H4, H7, H8 | 2_PIN_100mil | ext_pwr_conn | 3 |  |  | 0
PREC003SAAN-RC | Connector Header Through Hole 3 position 0.100" (2.54mm) | H5, H6 | 3_PIN_100mil | SW_3Pin_100mil_Switch | 2 |  |  | 0
1.9nH 1A | Inductor Chip 1.9nH 0.3nH Tolerance 2-Pin 0402 Paper T/R | L1, L2 | CAP_0402_1mm | LQG15WZ1N9S02D | 2 | 4 | 0.14 | 0.56 |  | Murata | LQG15WZ1N9S02D | Digi-Key
600ohm 500mA | Ferrite Beads 0603 600Ω ±25% DCR=0.38Ω 500mA | L3, L4 | IND_FERRITE_0603_1.6x0.4 | BLM18AG601SN1D | 2 | 5 | 0.1 | 0.5 | 0603 | Murata | BLM18AG601SN1D | Digi-Key
4.7uH 1.2A | Inductor FIXED IND 4.7UH 1.2A 186 MOHM | L5 | 2_IND_32X25 | LQH32PH4R7NNCL | 1 | 2 | 0.4 | 0.8 | Nonstandard | Murata | LQH32PH4R7NNCL | Digi-Key
1k 200mA | Ferrite Beads WE-CBF 0603 SMD Bead 100MHz 1000Ohm 200mA | L6 | CAP_0603_1MM | 74279266 | 1 | 2 | 0.18 | 0.36 | SMD/SMT | Wurth Electronics | 74279266 | Digi-Key
22uH | Inductor Power Shielded Wirewound 22uH 20% 1MHz Ferrite 0.87A 0.496Ohm DCR 1212 T/R | L7 | 2_IND_3x3 | VLS3015CX-220M-1 | 1 | 2 | 0.4 | 0.8 |  | TDK | VLS3015CX-220M-1 | Digi-Key
10uH 1A | Inductor Power Shielded Multi-Layer 10uH 20% 1MHz Metal 0.85A 0.46Ohm DCR 1008 T/R | L8 | 2_chip_2.5x2 | 1239AS-H-100M=P2 | 1 | 2 | 0.39 | 0.78 | 1008 | Murata | 1239AS-H-100M=P2 | Digi-Key
SHARP MEMORY Adafruit | Conn AV RCA (Phono) Plug 2 Cont Sz 0.125" Cbl Mnt Clamp Copper Alloy | LCD1 | LCD_SHARP_MEMORY_9_PIN | 3502 | 1 |  |  | 0 |  | Adafruit Industries | 3502 | Digi-Key
Green LED | Led Green Clear 0603 SMD | LED1, LED4, LED9, LED10, LED11, LED12 | LED_0603_RED_WL-SMCW | QBLP601-AG1 | 6 | 12 | 0.19 | 2.28 |  | QT-Brightek | QBLP601-AG1 | Digi-Key
150060YS75000 | Led, Yellow, 590 Nm, 2 V, 30 Ma, 120 Mcd Rohs Compliant: Yes | LED2, LED3 | LED_0603_RED_WL-SMCW | 150060YS75000 | 2 | 5 | 0.15 | 0.75 | 0603 | Wurth Electronics | 150060YS75000 | Digi-Key
150060RS75000 | LED Low-Power Uni-Color Red 630nm 2V 2-Pin Chip 0603(1608Metric) T/R | LED5, LED6, LED7, LED8 | LED_0603_RED_WL-SMCW | 150060RS75000 | 4 | 10 | 0.15 | 1.5 | 0603 | Wurth Electronics | 150060RS75000 | Digi-Key
4.7k 1% | Res Thick Film 0603 4.7K Ohm 1% 1/10W ±100ppm/°C Molded SMD Paper T/R | R1, R13 | CAP_0603_1MM | AF0603FR-074K7L | 2 | 10 | 0.061 | 0.61 | 0603 | Yageo | AF0603FR-074K7L | Digi-Key
1k 1% | Res 1K Ohm 1% 0.1W(1/10W) ±100ppm/C Pad SMD Automotive T/R | R2, R14, R15, R17, R18, R19, R30, R31, R32, R33, R36 | 2_Chip_0603_RMCF | RMCF0603FT1K00 | 11 | 25 | 0.017 | 0.425 | 0603 | Stackpole Electronics | RMCF0603FT1K00 | Digi-Key
1M 1% | Res 1M Ohm 1% 1/10W ±100ppm/°C Molded SMD Paper T/R | R3, R5, R6, R9 | 2_Chip_0603_RMCF | RMCF0603FT1M00 | 4 | 10 | 0.017 | 0.17 | 0603 | Stackpole Electronics | RMCF0603FT1M00 | Digi-Key
100 1% | Res 100 Ohm 1% 1/10W ±100ppm/°C Molded SMD SMD Paper T/R | R4, R7, R8, R10, R21 | 2_Chip_0603_RMCF | RMCF0603FT100R | 5 | 15 | 0.017 | 0.255 | 0603 | Stackpole Electronics | RMCF0603FT100R | Digi-Key
0 5% | Res 0 Ohms ±5% 0.063 W 0402 Thick Film Surface Mount Chip Resistor | R11, R12, R24, R49 | CAP_0402_1mm | RC1005J000CS | 4 | 10 | 0.042 | 0.42 | 0402 | Samsung | RC1005J000CS | Digi-Key
1 1% | Res 1 Ohm 1% 1/10W ±200ppm/°C Molded SMD SMD Paper T/R | R16, R20 | CAP_0603_1MM | RC0603FR-101RL | 2 | 10 | 0.048 | 0.48 | 0603 | Yageo | RC0603FR-101RL | Digi-Key
10M 1% | Res 10M Ohm 1% 1/10W ±200ppm/°C Molded SMD SMD Paper T/R | R22 | 2_Chip_0603_RMCF | RMCF0603FT10M0 | 1 | 10 | 0.025 | 0.25 | 0603 | Stackpole Electronics | RMCF0603FT10M0 | Digi-Key
2M 1% | RES 2M OHM 1% 1/10W 0603 | R23 | 2_Chip_0603_RMCF | RMCF0603FT2M00 | 1 | 10 | 0.025 | 0.25 | 0603 | Stackpole Electronics | RMCF0603FT2M00 | Digi-Key
7.87M 1% | Res 7.87M Ohm 1% 1/10W ±200ppm/°C Molded SMD SMD Paper T/R | R25 | 2_Chip_0603_RMCF | RMCF0603FT7M87 | 1 | 10 | 0.025 | 0.25 | 0603 | Stackpole Electronics | RMCF0603FT7M87 | Digi-Key
20 1% | Res High Voltage 0603 20 Ohm 1/10W 1% SMD | R26 | 2_Chip_0603_RMCF | KTR03EZPF20R0 | 1 | 3 | 0.17 | 0.51 | 0603 | Rohm | KTR03EZPF20R0 | Digi-Key
7.32M 1% | Res 7.32M Ohm 1% 1/10W ±200ppm/°C Molded SMD SMD Paper T/R | R27, R35 | 2_Chip_0603_RMCF | RMCF0603FT7M32 | 2 | 10 | 0.025 | 0.25 | 0603 | Stackpole Electronics | RMCF0603FT7M32 | Digi-Key
1.43M 1% | Res 1.43M Ohm 1% 1/10W ±200ppm/°C Molded SMD SMD Paper T/R | R28 | 2_Chip_0603_RMCF | RMCF0603FT1M43 | 1 | 10 | 0.025 | 0.25 | 0603 | Stackpole Electronics | RMCF0603FT1M43 | Digi-Key
8.06M 1% | Res 8.06M Ohm 1% 1/10W ±200ppm/°C Molded SMD SMD Paper T/R | R29 | 2_Chip_0603_RMCF | RMCF0603FT8M06 | 1 | 10 | 0.025 | 0.25 | 0603 | Stackpole Electronics | RMCF0603FT8M06 | Digi-Key
5.62M 1% | Res 5.62M Ohm 1% 1/10W ±200ppm/°C Molded SMD SMD Paper T/R | R34 | 2_Chip_0603_RMCF | RMCF0603FT5M62 | 1 | 10 | 0.025 | 0.25 | 0603 | Stackpole Electronics | RMCF0603FT5M62 | Digi-Key
4.87M 1% | Res 4.87M Ohm 1% 1/10W ±200ppm/°C Molded SMD SMD Paper T/R | R37 | 2_Chip_0603_RMCF | RMCF0603FT4M87 | 1 | 10 | 0.025 | 0.25 | 0603 | Stackpole Electronics | RMCF0603FT4M87 | Digi-Key
3k 1% | Res 3000Ω ± 1.00% 0.1W ± 100ppm/℃ 0603 | R39 | CAP_0603_1MM | RC0603FR-073KL | 1 | 10 | 0.024 | 0.24 | 0603 | Yageo | RC0603FR-073KL | Digi-Key
4.42M 1% | Res 4.42M Ohm 1% 1/10W ±200ppm/°C Molded SMD SMD Paper T/R | R40 | 2_Chip_0603_RMCF | RMCF0603FT4M42 | 1 | 10 | 0.025 | 0.25 | 0603 | Stackpole Electronics | RMCF0603FT4M42 | Digi-Key
Solar Cell | MONOCRYS SOLAR CELL 30.7MW 690MV | S1, S2, S3, S4, S5, S6, S7, S8, S9, S10 | KXOB25-14X1F | KXOB25-14X1F | 10 | 10 | 2.296 | 22.96
TL3301DF160QG | Tactile Switch SPST-NO Top Actuated Surface Mount | SW1, SW2, SW3, SW4, SW5 | SW_TL3301DF160QG | TL3301DF160QG | 5 | 10 | 0.447 | 4.47
10x Probe TP | Test Point 300 mil centers | TP1, TP2, TP3, TP4, TP5, TP6, TP7, TP8, TP9, TP10, TP11, TP12, TP13, TP14, TP15, TP16, TP17, TP18, TP19, TP20, TP21, TP22, TP23, TP24, TP25 | TP10x_Probe | TP_10x_Probe | 25 |  |  | 0
Load SW | 5.5-V, 0.1-A, 500-mΩ, load switch with current limit and active low enable 5-SC70 -40 to 85 | U1, U10, U11, U14 | SOT65P210X110-5N | TPS22942DCKR | 3 | 6 | 1.24 | 7.44 | SC | Texas Instruments | TPS22942DCKR | Digi-Key
ESD-SP1001 | TVS DIODE 5.5VWM 13VC SC70-5 | U2 | SOT65P210X110-5N | SP1001-04JTG | 1 | 2 | 0.61 | 1.22 | SC | Littelfuse | SP1001-04JTG | Digi-Key
EFR32BG13 | Blue Gecko QFN48 2.4 G 19 dB BLE/Proprietary 512 kB 64 kB(RAM) 31GPIO | U3 | 48-QFN_7x7 | EFR32BG13P732F512GM48-D | 1 |  |  | 0 |  | Silicon Labs | EFR32BG13P732F512GM48-D | Digi-Key
ESD-SP1003 | TVS DIODE 5VWM 12VC SOD723 | U4, U5, U6 | Littelfuse_Inc_SP1003_MFG | SP1003-01DTG | 3 | 6 | 0.57 | 3.42 |  | Littelfuse | SP1003-01DTG | Digi-Key
BQ25570 | Switching Battery Charger Li-Ion/Li-Pol/Supercapacitor 110mA 2.2V to 5.5V 20-Pin VQFN EP T/R | U7 | 21_QFN_35x35 | BQ25570RGRT | 1 | 2 | 8.95 | 17.9 | VQFN | Texas Instruments | BQ25570RGRT | Digi-Key
AS5147P | Rotary Position Sensor 5.5V/3.6V Digital Output Automotive 14-Pin TSSOP T/R | U8, U9 | 14-TSOP_5x4_4 | AS5147P-HTSM | 1 | 2 | 9.56 | 19.12 |  | ams | AS5147P-HTSM | Digi-Key
Ultrasonic Sensor |  | U13 | 7_PIN_100MIL | Ultrasonic Sensor | 1 |  |  | 0
BNO005 |  | U15 | LGA28R50P4X10_380X520X100 | BNO055 | 1 |  |  | 0
38.4MHz | Crystal 38.4000MHZ 10PF SMD | X1 | OSC_38.4MHz | RH100-38.400-10-F-1010-TR | 1 | 2 | 0.39 | 0.78 |  | Raltron Electronics | RH100-38.400-10-F-1010-TR | Digi-Key
32.768 kHz | Oscillator XO 0.032768MHz ±25ppm 15pF CMOS 60% 1.8V 4-Pin SMD T/R | X2 | OSC_ASDDV-48.000MHZ-LC-T | ASDK2-32.768KHZ-LR-T3 | 1 | 2 | 0.97 | 1.94 | SMD/SMT | Abracon | ASDK2-32.768KHZ-LR-T3 | Digi-Key
Male pin headers |  |  |  | 77311-418-00LF‎ |  | 30 | 0.054 | 1.62 |  | Amphenol CS (FCI)
LiPo Battery |  |  |  | LP802036JU+PCM+2 WIRES 50MM |  | 1 | 9.51 | 9.51 |  | Jauch Quartz
 |  |  |  |  |  |  | Total Amount | 133.62
Parts Acquired from Professor Randy
EFR32BG13 |  |  |  |  |  | 2 | 7 | 14
BNO055 |  |  |  |  |  | 2 | 9.3 | 18.6
 |  |  |  |  |  |  | Total BOM amount | 166.22

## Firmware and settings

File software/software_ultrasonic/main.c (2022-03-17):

/***************************************************************************//**
 * @file
 * @brief main() function.
 *******************************************************************************
 * # License
 * <b>Copyright 2020 Silicon Laboratories Inc. www.silabs.com</b>
 *******************************************************************************
 *
 * SPDX-License-Identifier: Zlib
 *
 * The licensor of this software is Silicon Laboratories Inc.
 *
 * This software is provided 'as-is', without any express or implied
 * warranty. In no event will the authors be held liable for any damages
 * arising from the use of this software.
 *
 * Permission is granted to anyone to use this software for any purpose,
 * including commercial applications, and to alter it and redistribute it
 * freely, subject to the following restrictions:
 *
 * 1. The origin of this software must not be misrepresented; you must not
 *    claim that you wrote the original software. If you use this software
 *    in a product, an acknowledgment in the product documentation would be
 *    appreciated but is not required.
 * 2. Altered source versions must be plainly marked as such, and must not be
 *    misrepresented as being the original software.
 * 3. This notice may not be removed or altered from any source distribution.
 *
 * Date:        08-07-2021
 * Author:      Dave Sluiter
 * Description: This code was created by the Silicon Labs application wizard
 *              and started as "Bluetooth - SoC Empty".
 *              It is to be used only for ECEN 5823 "IoT Embedded Firmware".
 *              The MSLA referenced above is in effect.
 *              
 *              This code was written with:
 *                  Gecko SDK 3.2.1
 *                  GNU ARM 10.2.1
 *
 ******************************************************************************/

#include "main.h"

// Include logging for this file
#define INCLUDE_LOG_DEBUG 1
#include "src/log.h"
#include "src/imu.h"




int main(void)
{

  // Initialize Silicon Labs device, system, service(s) and protocol stack(s).
  // Note that if the kernel is present, processing task(s) will be created by
  // this call.
  sl_system_init();

  // Initialize the application. For example, create periodic timer(s) or
  // task(s) if the kernel is present.
  // Students: Place all of your 1 time initialization code in this function.
  //           See app.c
  app_init();

//  init_imu();

#if defined(SL_CATALOG_KERNEL_PRESENT)

  // Start the kernel. Task(s) created in app_init() will start running.
  sl_system_kernel_start();

#else // SL_CATALOG_KERNEL_PRESENT

  // The so-called super-loop, sometimes called: "the main while(1) loop"
  while (1) {

      // Do not remove this call: Silicon Labs components process action routine
      // must be called from the super loop.
      // Students: This call will eventually call the function sl_bt_on_event()
      // defined in app.c which we will discuss in lecture and learn more about
      // in later programming assignments. Do not remove this call.
      sl_system_process_action();

      // Application process. See app.c
      app_process_action();

#if defined(SL_CATALOG_POWER_MANAGER_PRESENT)
      // Let the CPU go to sleep if the system allows it.
      sl_power_manager_sleep();
#endif

  } // while

#endif // SL_CATALOG_KERNEL_PRESENT

} // main()



//
///***************************************************************************//**
// * @file main_tg11.c
// * @brief This project reads input on the UART RX port and echoes it back to the
// * TX port one line at a time. It does not use the VCOM or stdio. See readme.txt
// * for details.
// *******************************************************************************
// * # License
// * <b>Copyright 2020 Silicon Laboratories Inc. www.silabs.com</b>
// *******************************************************************************
// *
// * SPDX-License-Identifier: Zlib
// *
// * The licensor of this software is Silicon Laboratories Inc.
// *
// * This software is provided 'as-is', without any express or implied
// * warranty. In no event will the authors be held liable for any damages
// * arising from the use of this software.
// *
// * Permission is granted to anyone to use this software for any purpose,
// * including commercial applications, and to alter it and redistribute it
// * freely, subject to the following restrictions:
// *
// * 1. The origin of this software must not be misrepresented; you must not
// *    claim that you wrote the original software. If you use this software
// *    in a product, an acknowledgment in the product documentation would be
// *    appreciated but is not required.
// * 2. Altered source versions must be plainly marked as such, and must not be
// *    misrepresented as being the original software.
// * 3. This notice may not be removed or altered from any source distribution.
// *
// *******************************************************************************
// * # Evaluation Quality
// * This code has been minimally tested to ensure that it builds and is suitable
// * as a demonstration for evaluation purposes only. This code will be maintained
// * at the sole discretion of Silicon Labs.
// ******************************************************************************/
//
//#include "em_device.h"
//#include "em_chip.h"
//#include "em_emu.h"
//#include "em_cmu.h"
//#include "em_gpio.h"
//#include "em_usart.h"
//
//#include "bsp.h"
//
//// Size of the buffer for received data
//#define BUFLEN  80
//
//// Receive data buffer
//uint8_t buffer[BUFLEN];
//
//// Current position ins buffer
//uint32_t inpos = 0;
//uint32_t outpos = 0;
//
//// True while receiving data (waiting for CR or BUFLEN characters)
//bool receive = true;
//
///**************************************************************************//**
// * @brief
// *    GPIO initialization
// *****************************************************************************/
//void initGpio(void)
//{
//  CMU_ClockEnable(cmuClock_GPIO, true);
//
//  // Configure VCOM transmit pin to board controller as an output
//  GPIO_PinModeSet(BSP_BCC_TXPORT, BSP_BCC_TXPIN, gpioModePushPull, 1);
//
//  // Configure VCOM reeive pin from board controller as an input
//  GPIO_PinModeSet(BSP_BCC_RXPORT, BSP_BCC_RXPIN, gpioModeInput, 0);
//
//  // Enable VCOM connection to board controller
//  GPIO_PinModeSet(BSP_BCC_ENABLE_PORT, BSP_BCC_ENABLE_PIN, gpioModePushPull, 1);
//}
//
///**************************************************************************//**
// * @brief
// *    USART1 initialization (VCOM on xG1/xG12/xG13 boards)
// *****************************************************************************/
//void initUsart1(void)
//{
//  CMU_ClockEnable(cmuClock_USART1, true);
//
//  // Default asynchronous initializer (115.2 Kbps, 8N1, no flow control)
//  USART_InitAsync_TypeDef init = USART_INITASYNC_DEFAULT;
//
//  // Configure and enable USART1
//  USART_InitAsync(USART1, &init);
//
//  // Enable NVIC USART sources
//  NVIC_ClearPendingIRQ(USART1_IRQn);
//  NVIC_EnableIRQ(USART1_IRQn);
//
//  // Enable RX and TX for USART1 VCOM connection
//  USART1->ROUTELOC0 = BSP_BCC_RX_LOCATION | BSP_BCC_TX_LOCATION;
//  USART1->ROUTEPEN |= USART_ROUTEPEN_RXPEN | USART_ROUTEPEN_TXPEN;
//}
//
///**************************************************************************//**
// * @brief
// *    The USART1 receive/transmit interrupt processes characters.
// *****************************************************************************/
//void USART1_IRQHandler(void)
//{
//  // In the receive state
//  if (receive)
//  {
//    // Get the character just received
//    buffer[inpos] = USART1->RXDATA;
//
//    // Exit loop on new line or buffer full
//    if ((buffer[inpos] != '\r') && (inpos < BUFLEN))
//      inpos++;
//    else
//      receive = false;   // Stop receiving on CR
//  }
//  // In the transmit state
//  else
//  {
//    // Send a previously received character
//    if (outpos < inpos)
//      USART1->TXDATA = buffer[outpos++];
//    else
//    /*
//     * Need to disable the transmit buffer level interrupt in this IRQ
//     * handler when done or it will immediately trigger again upon exit
//     * even though there is no data left to send.
//     */
//    {
//      receive = true;   // Go back into receive when all is sent
//      USART_IntDisable(USART1, USART_IEN_TXBL);
//    }
//  }
//}
//
///**************************************************************************//**
// * @brief
// *    Main function
// *****************************************************************************/
//int main(void)
//{
//  uint32_t i;
//
//  // Chip errata
//  CHIP_Init();
//
//  // Initialize GPIO and USART0
//  initGpio();
//  initUsart1();
//
//  while (1)
//  {
//    // Zero out buffer
//    for (i = 0; i < BUFLEN; i++)
//      buffer[i] = 0;
//
//    // Enable receive data valid interrupt
//    USART_IntEnable(USART1, USART_IEN_RXDATAV);
//
//    // Wait in EM1 while receiving to reduce current draw
//    while (receive)
//      EMU_EnterEM1();
//
//    // Disable receive data valid interrupt
//    USART_IntDisable(USART1, USART_IEN_RXDATAV);
//
//    // Enable transmit buffer level interrupt
//    USART_IntEnable(USART1, USART_IEN_TXBL);
//
//    // Wait in EM1 while transmitting to reduce current draw
//    while (!receive)
//      EMU_EnterEM1();
//
//    // Reset buffer indices
//    inpos = outpos = 0;
//  }
//}

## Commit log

2022-02-12 Project update 2
    [cubit_energy_calculations.xlsx, cubit_gantt_chart.xlsx]
2022-02-12 Project Update 3
    [cubit_battery_supercap.xlsx]
2022-02-15 initial code
    [Assignment5-BLEEventSchedulerGuidance.xlsx, Assignment6-ClientCommandTableForA7.xlsx, ClientCommandTableA9.xlsx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]
2022-02-17 Project update 4
    [Timing Information.xlsx, bq25570SolarAppDesign.xlsx, bq25570_Design_Help.xlsx]
2022-02-20 U5: lcd driver, bulk capacitor
    [cubit_gantt_chart.xlsx]
2022-02-22 updated qfn, f-ant footprint, added usb in altium library
2022-02-25 IMU and Mag encoder bringup
2022-02-26 lib, sch in progress: work not merged
    [Sheet1.SchDoc, lpedt_project_board_cubit.PrjPcb]
2022-02-26 integrated libraries, general and efr32 power schematic
2022-02-27 schematic update
    [efr32_general.SchDoc, efr32_ioport.SchDoc, efr32_radio_interface.SchDoc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]
2022-02-27 library update, power and gpio schematic
    [efr32_general.SchDoc, efr32_ioport.SchDoc, power_management.SchDoc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]
2022-02-27 Sensors and ioports schematic update
    [Sensors.SchDoc, Sheet1.SchDoc, efr32_ioport.SchDoc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]
2022-02-28 multiplexed mag enc and multi power supply
    [Block_Diagram.SchDoc, Mag_Enc_Sensors.SchDoc, Schematic review_checklist _20210225.xlsx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]
2022-03-17 hardware layout prefinal + software mag_enc and ultrasonic raw
    [Assignment5-BLEEventSchedulerGuidance.xlsx, Assignment6-ClientCommandTableForA7.xlsx, Block_Diagram.SchDoc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]
2022-03-17 layout v2.0 post final review
    [Assignment5-BLEEventSchedulerGuidance.xlsx, Assignment6-ClientCommandTableForA7.xlsx, ClientCommandTableA9.xlsx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]
2022-11-01 hardware design updated
    [Block_Diagram.SchDoc, Mag_Enc_Sensors.SchDoc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]
2022-11-01 added software files
    [Assignment5-BLEEventSchedulerGuidance.xlsx, Assignment6-ClientCommandTableForA7.xlsx, ClientCommandTableA9.xlsx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]
2023-03-19 "added sensor images"
2023-03-22 added schematic image
2023-03-22 added images for schematic wiki page
